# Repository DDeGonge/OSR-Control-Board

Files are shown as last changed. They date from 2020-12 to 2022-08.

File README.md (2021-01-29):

# OSR-Control-Board
Open Source Robotics Control Board - The cheap, overpowered, easy to use robotics controller.

## BOM
Latest BOM can be found [here](https://octopart.com/bom-tool/g8IoScnJ)

## Bootloader
Flashing instructions are found [here](https://learn.adafruit.com/how-to-program-samd-bootloaders/programming-the-bootloader-with-atmel-studio). Follow directions for Feather M4. Notch on flex cable faces AWAY from mcu.

## Random Stuff
Generate MD5 sum for packages - `CertUtil -hashfile C:\TEMP\MyDataFile.img MD5`

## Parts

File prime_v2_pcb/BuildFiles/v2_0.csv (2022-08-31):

Id | Designator | Package | Quantity | Designation | Supplier and ref
1 | J10,J6,J3,J9,J7,J5,J4,J1 | PinHeader_1x04_P2.54mm_Vertical | 8 | Conn_01x04
2 | J14,J12,J11,J8 | PinHeader_1x05_P2.54mm_Vertical | 4 | Conn_01x05
3 | A1,A3,A2 | Pololu_Breakout-20_15.2x20.3mm | 3 | Pololu_Breakout_TMC5160
4 | C3,C2,C1,C49,C19,C30 | CP_Elec_6.3x7.7 | 6 | 47uF
5 | C31 | C_0805_2012Metric | 1 | 10uF
6 | U3 | MUB_v1 | 1 | MUBv1
7 | U2,U1 | QFN-48-1EP_7x7mm_P0.5mm_EP5.3x5.3mm | 2 | TMC2041-LA
8 | J2 | 691313710002 | 1 | 691313710002
9 | G*** | smol_logo | 1 | LOGO
10 | G*** | logo | 1 | LOGO
11 | R12,R11,R10,R9,R7,R6,R5,R4 | R_0805_2012Metric | 8 | 0R2
12 | R8,R3 | R_0603_1608Metric | 2 | 2R2
13 | C50,C42,C27,C22,C21,C20,C18,C17,C13,C12 | C_0603_1608Metric | 10 | 100nF
14 | C26,C16 | C_0603_1608Metric | 2 | 22nF
15 | C24,C15 | C_0603_1608Metric | 2 | 470nF
16 | C23,C14 | C_1206_3216Metric | 2 | 2.2uF
17 | J22 | PinSocket_1x06_P2.54mm_Vertical | 1 | Conn_01x06
18 | J16,J15 | PinHeader_1x03_P2.54mm_Vertical | 2 | Conn_01x03
19 | J20,J19,J18,J17 | MountingHole_2.7mm_M2.5_DIN965_Pad | 4 | Hole
20 | J13 | PinHeader_1x10_P2.54mm_Vertical | 1 | Conn_01x10

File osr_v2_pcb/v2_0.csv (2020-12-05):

Id | Designator | Package | Quantity | Designation | Supplier and ref
1 | J6 | 2002112100010C4LF | 1 | 20021121-00010C4LF
2 | R22,R18,R16,R15,R2,R1 | R_0603_1608Metric | 6 | 10k
3 | R21 | R_0603_1608Metric | 1 | 100k
4 | J1 | 475710001 | 1 | 47571-0001
5 | L3,L2,L1 | L_0805_2012Metric | 3 | 10uH
6 | IC1 | SOT95P280X100-6N | 1 | AP63205WU-7
7 | C36,C35,C34,C31,C2 | C_0805_2012Metric | 5 | 10uF
8 | C7,C11,C10,C9,C8,C6,C5,C3,C1 | C_0603_1608Metric | 9 | 1uF
9 | C4,C28,C27,C25,C22,C21,C19,C18,C16,C13,C12 | C_0603_1608Metric | 11 | 100nF
10 | J22 | PinSocket_1x06_P2.54mm_Vertical | 1 | Conn_01x06
11 | J7,J21,J9,J8 | PinHeader_1x02_P2.54mm_Vertical | 4 | Conn_01x02
12 | D4,D3 | D_SOD-123F | 2 | CGRTS4004-HF
13 | R20,R19,R14,R13,R17 | R_0603_1608Metric | 5 | 174
14 | D2,D1 | LED_0603_1608Metric | 2 | LED
15 | G*** | smol_logo | 1 | LOGO
16 | G*** | logo | 1 | LOGO
17 | IC2 | QFN-64-1EP_9x9mm_P0.5mm_EP6x6mm_ThermalVias | 1 | ATSAMD51J19A-MU
18 | S1 | KMR421GULCLFS | 1 | KMR243GLFG
19 | J11,J10,J5,J4 | PinHeader_1x04_P2.54mm_Vertical | 4 | Conn_01x04
20 | J14 | PinSocket_1x20_P2.54mm_Vertical | 1 | Conn_01x20
21 | J16,J15,J13,J12 | PinHeader_1x03_P2.54mm_Vertical | 4 | Conn_01x03
22 | C33,C32 | C_0603_1608Metric | 2 | 22pF
23 | J2 | BarrelJack_Wuerth_6941xx301002 | 1 | Conn_01x02
24 | Y1 | LFXTAL009678REEL | 1 | LFXTAL009678REEL
25 | Q2,Q1 | NVTFS6H854NTAG | 2 | NVTFS5C680NLTAG
26 | R12,R11,R10,R9,R7,R6,R5,R4 | R_0805_2012Metric | 8 | 0R2
27 | R8,R3 | R_0603_1608Metric | 2 | 2R2
28 | C30,C29,C20 | CP_Elec_6.3x7.7 | 3 | 47uF
29 | C26,C17 | C_0603_1608Metric | 2 | 22nF
30 | C24,C15 | C_0603_1608Metric | 2 | 470nF
31 | C23,C14 | C_1206_3216Metric | 2 | 4.7uF
32 | U3 | SOT-23-5 | 1 | AP2112K-3.3
33 | J3 | 47346-0001 | 1 | 47346-0001
34 | U2,U1 | QFN-48-1EP_7x7mm_P0.5mm_EP5.3x5.3mm_ThermalVias | 2 | TMC2041-LA
35 | J20,J19,J18,J17 | MountingHole_2.7mm_M2.5_DIN965_Pad | 4 | Hole

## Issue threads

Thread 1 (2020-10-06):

No general use power/ground pins

DDeGonge, 2020-10-06:
Add some 3v3, 5v, vin, and gnd pins in a cluster somewhere so peripherals can more easily access power and ground

DDeGonge, 2020-10-10:
Added 1x VDC, 1x 5v, 2x 3v3, 2x gnd to a new header

Closed 2020-10-10.

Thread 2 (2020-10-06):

Add better stepper driver protection

DDeGonge, 2020-10-06:
Low hanging fruit is added esd protection. But maybe also add varistors for protection against accidental disconnects while powered.

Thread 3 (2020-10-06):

Upgrade generic gate mosfets

DDeGonge, 2020-10-06:
Use DMT3006LDK-7 instead of NVTFS5C680NLTAG

30V instead of 60V which makes more sense for this pcb that operates at 6-24v
17A continuous instead of 8A because...more better
Only a few cents more

DDeGonge, 2020-11-18:
DMT3006LDK-7 has stock problems and I don't know why I'd ever need such a high power gate..but will leave this open for future changes

Closed 2020-11-18.

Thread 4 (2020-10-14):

Add better battery support

DDeGonge, 2020-10-14:
Include a voltage divider so battery voltage can be measured directly, with support for up to a 6s battery.

Stretch goal is to add balance charger but this will probably be too expensive.

DDeGonge, 2020-12-05:
hooked up vin voltage divider to B1 (pin 62)

Closed 2020-12-05.

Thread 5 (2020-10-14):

Add fuse protection on input

DDeGonge, 2020-10-14:
Safety is number one priority.

Not sure of the value since this board is hangry for power.

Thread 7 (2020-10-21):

Find black sense resistors

DDeGonge, 2020-10-21:
The green ones are ugly and I'm vain

DDeGonge, 2020-10-27:
Replaced with ERJ-6DSFR20V. Also now 1/2W instead of 1/3W.

Closed 2020-10-27.

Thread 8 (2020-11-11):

Change 5V reg from linear to buck

DDeGonge, 2020-11-11:
5V isn't actually used by any onboard devices so it's fine if it isn't perfectly stable. Retain lreg for 3v3 line.

Closed 2020-11-18.

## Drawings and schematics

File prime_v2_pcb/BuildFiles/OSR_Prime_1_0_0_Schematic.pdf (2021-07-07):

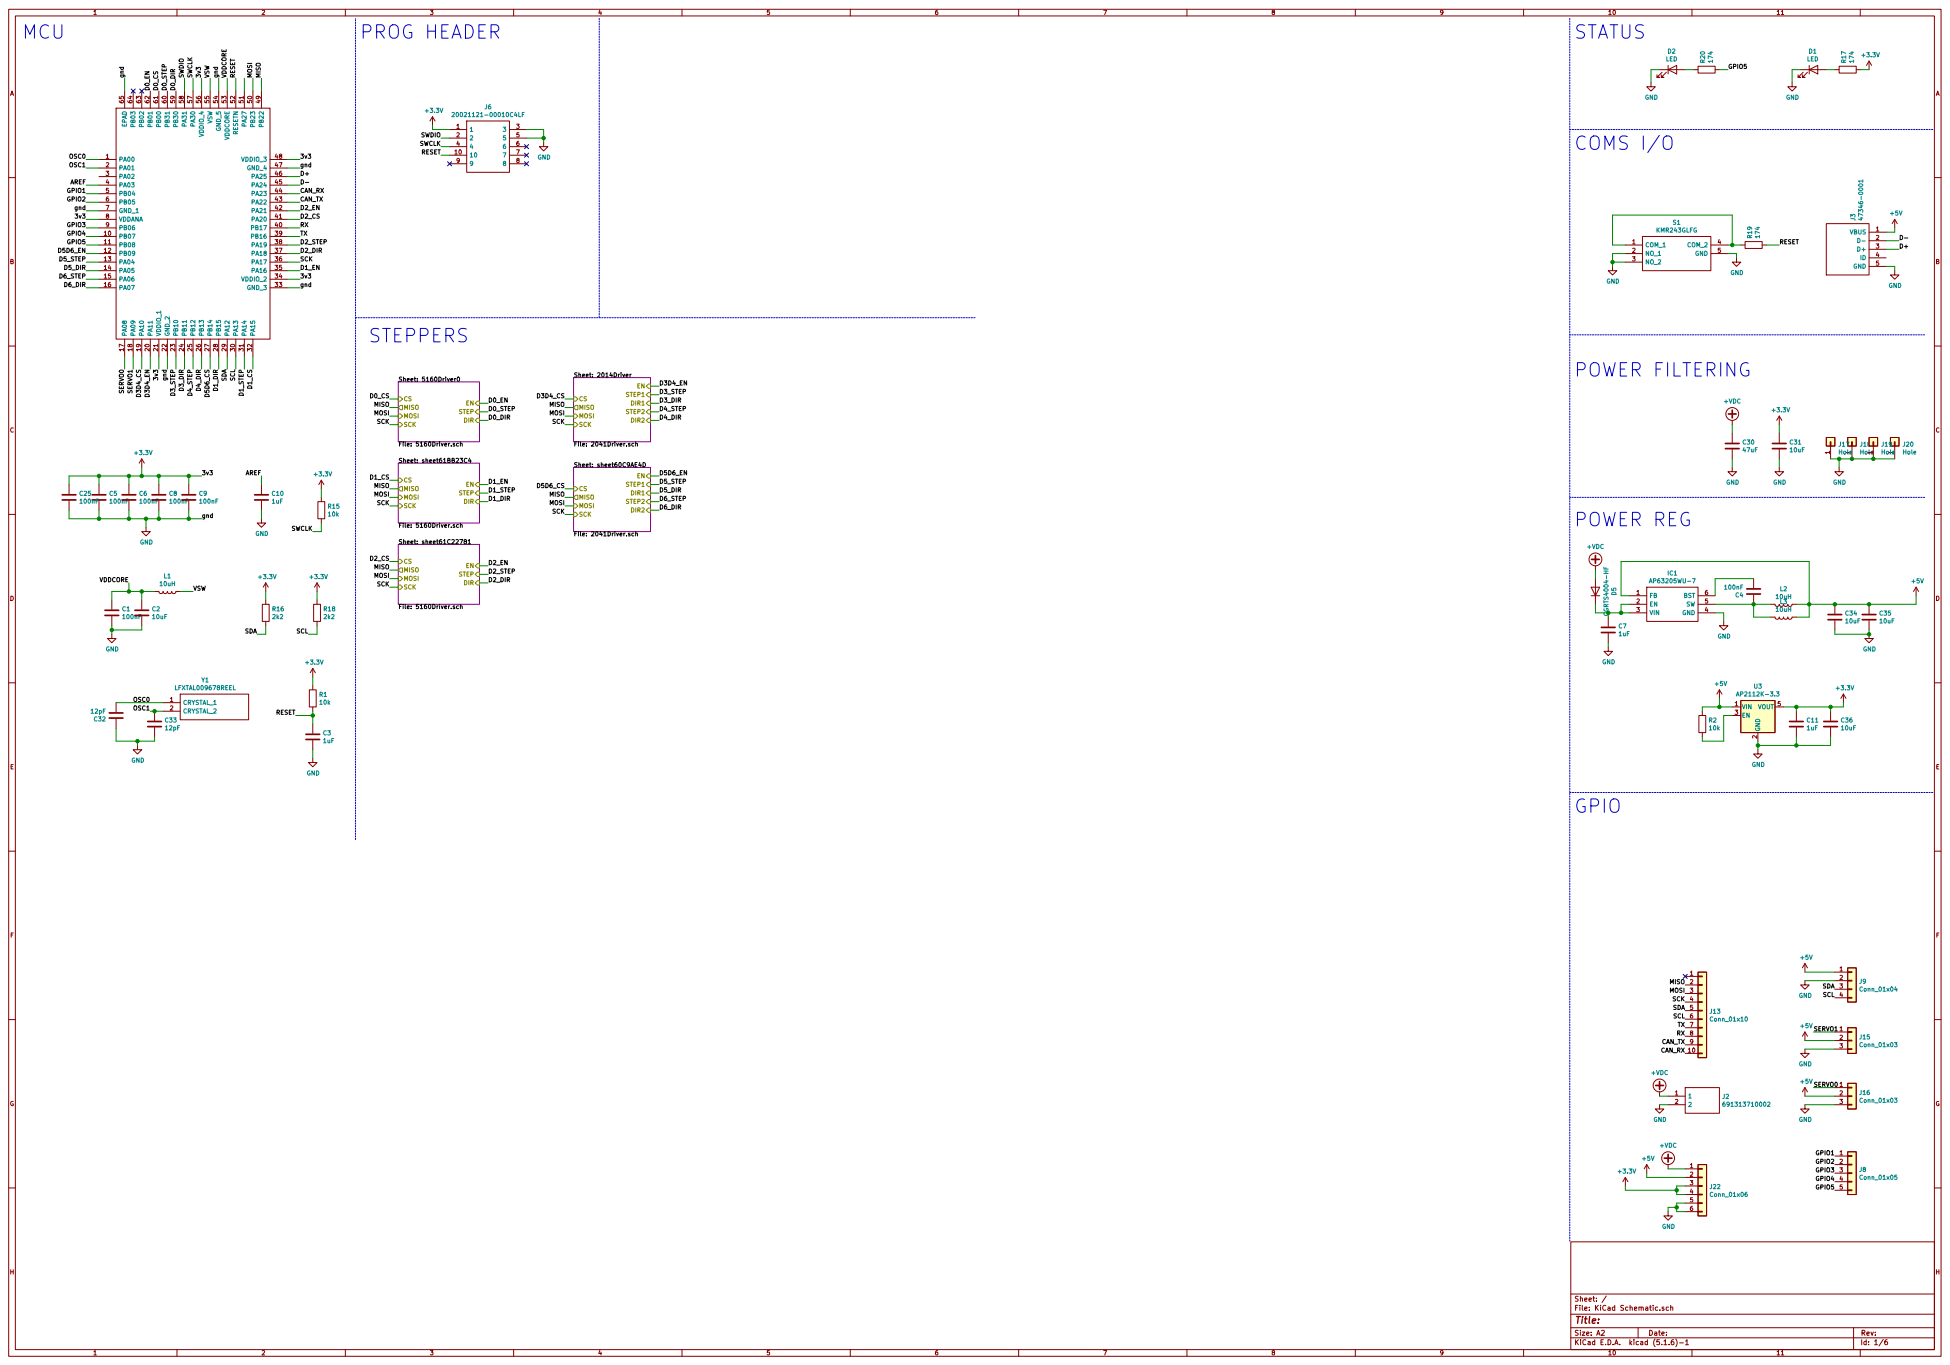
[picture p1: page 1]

Sheet: 5160Driver0 File: 5160Driver.sch SCK MOSI MISO

Sheet: sheet61BB23C4 File: 5160Driver.sch SCK MOSI MISO

Sheet: sheet61C22781 File: 5160Driver.sch SCK MOSI MISO

Id: 1/6 Title: File: KiCad Schematic.sch Sheet: /

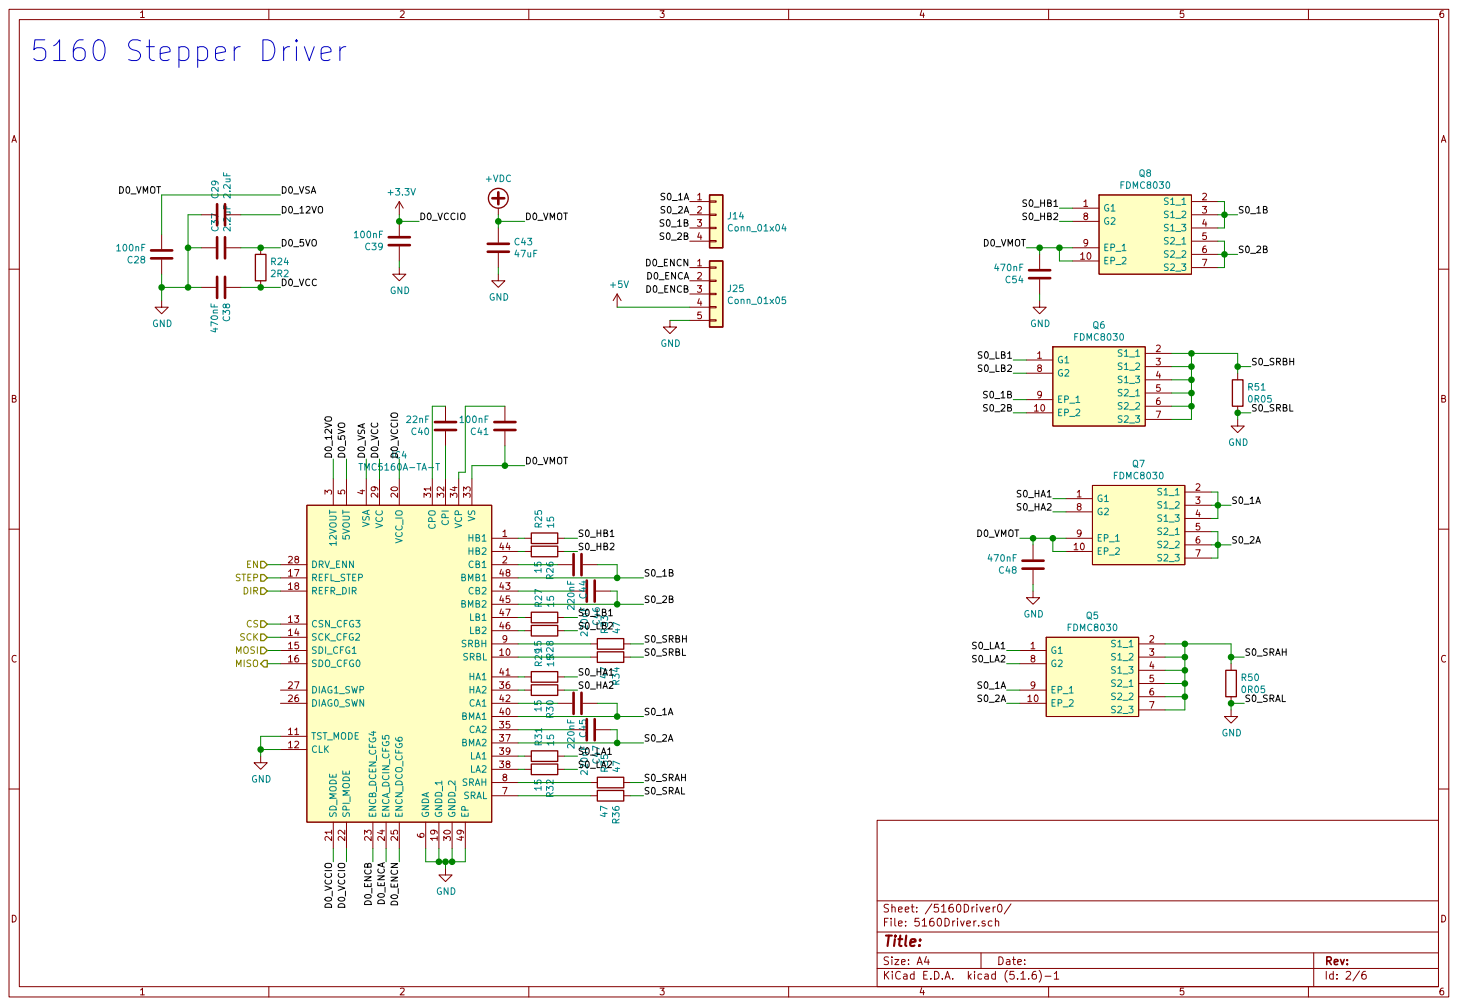
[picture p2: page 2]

EN MISO MOSI CS
STEP
SCK DIR

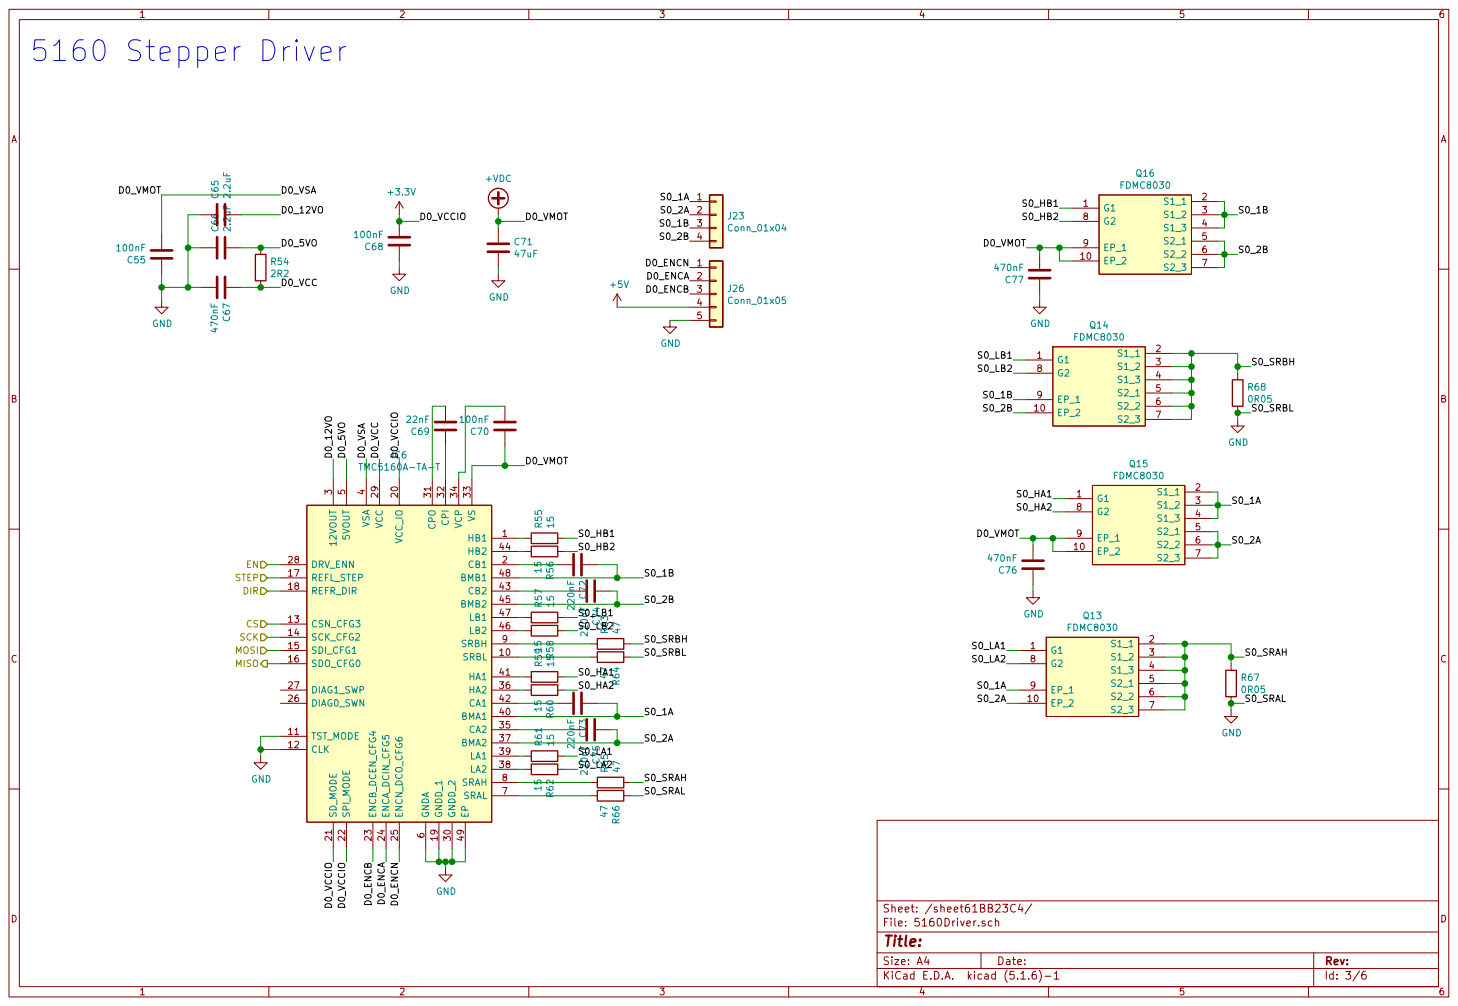
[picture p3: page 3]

EN MISO MOSI CS
STEP
SCK DIR

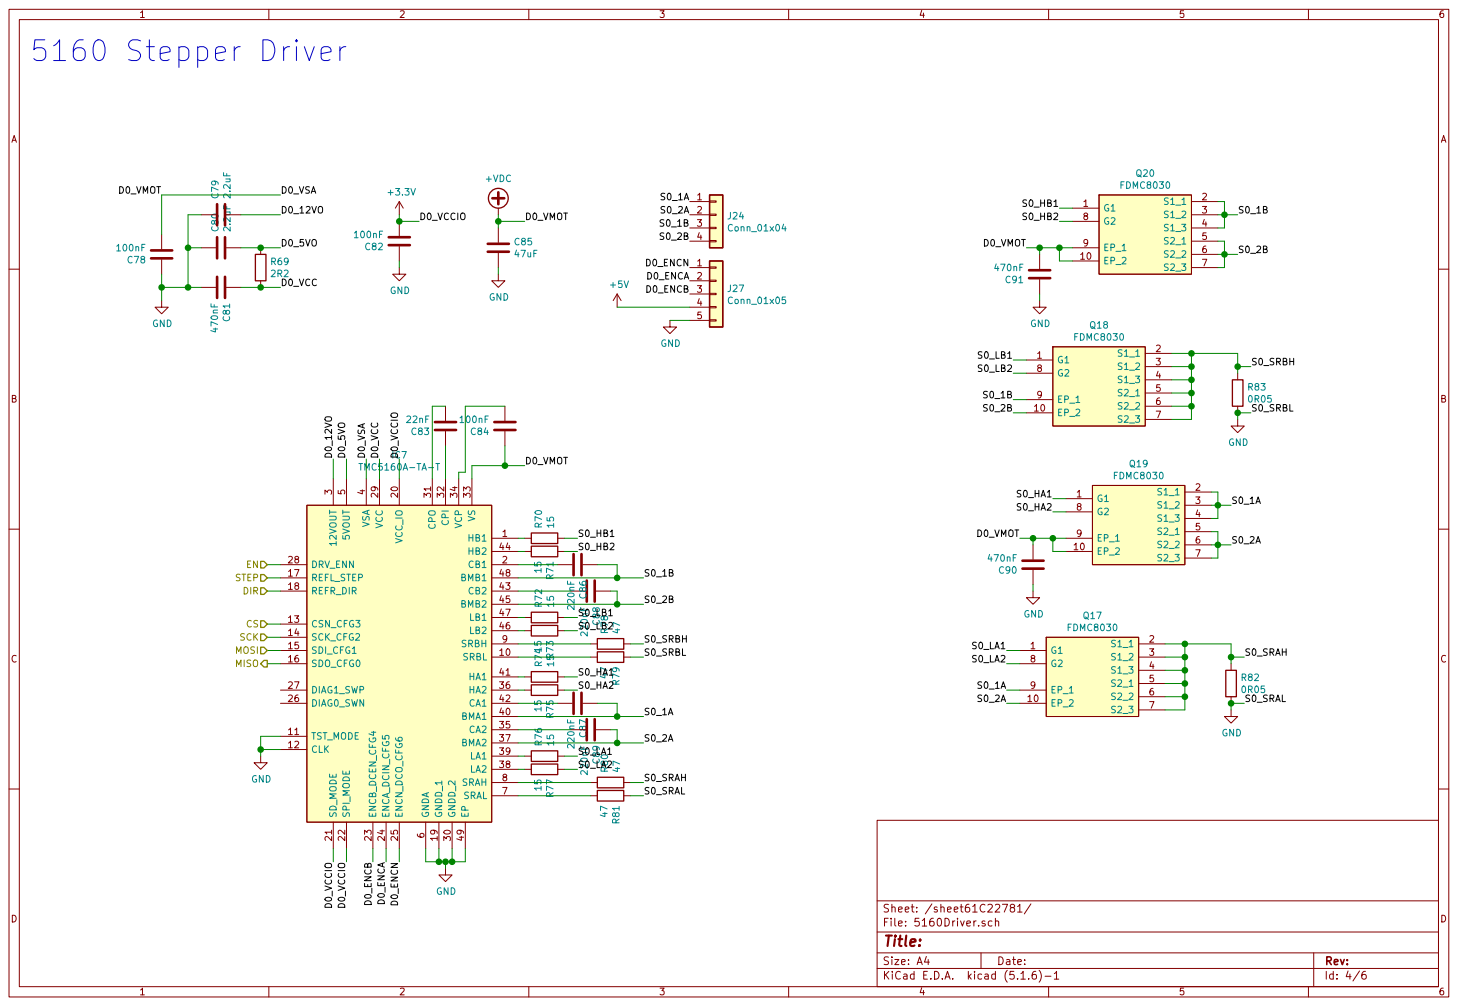
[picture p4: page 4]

EN MISO MOSI CS
STEP
SCK DIR

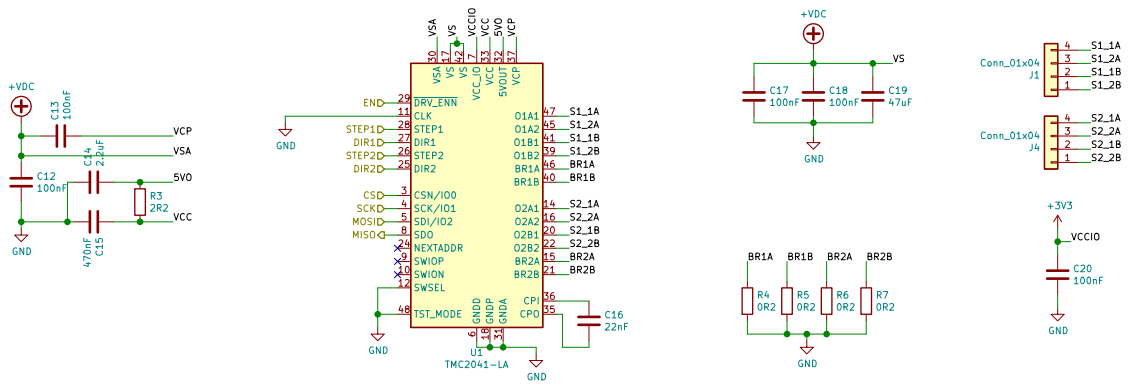
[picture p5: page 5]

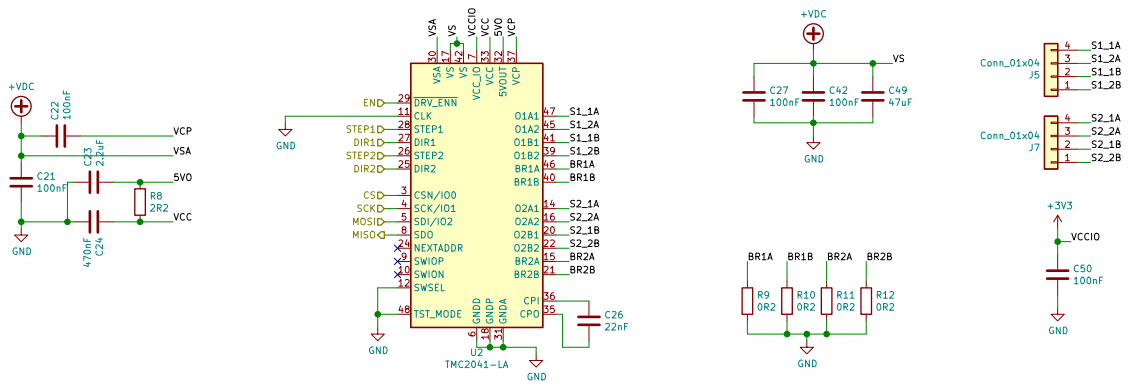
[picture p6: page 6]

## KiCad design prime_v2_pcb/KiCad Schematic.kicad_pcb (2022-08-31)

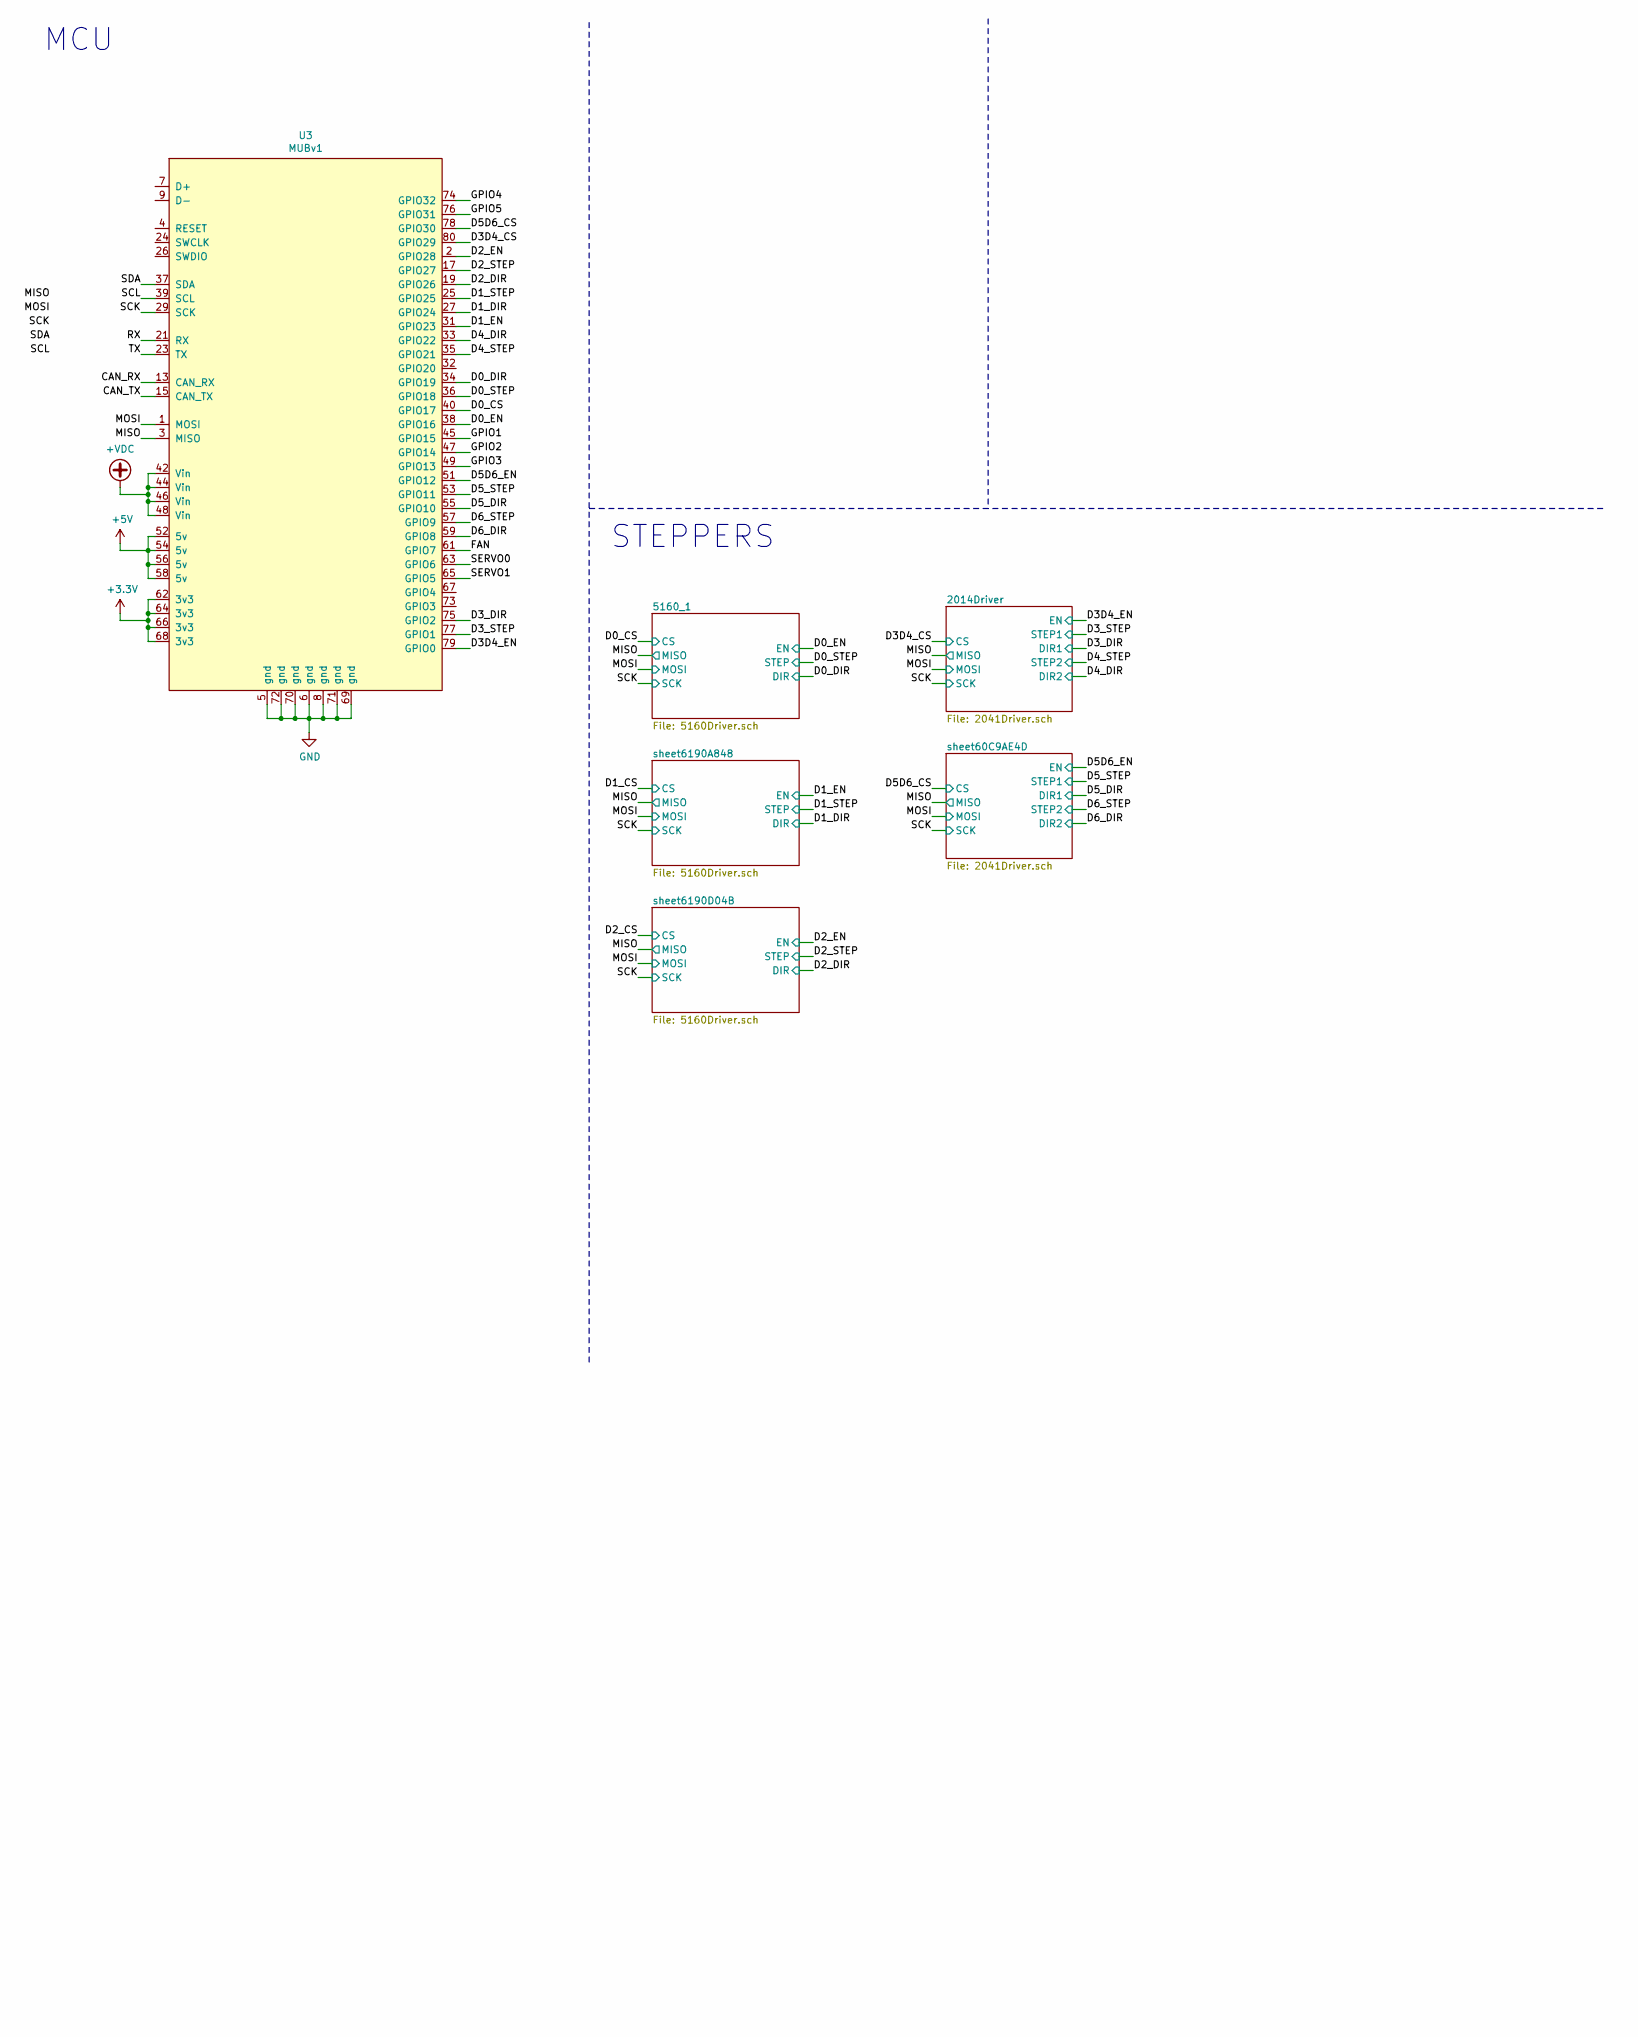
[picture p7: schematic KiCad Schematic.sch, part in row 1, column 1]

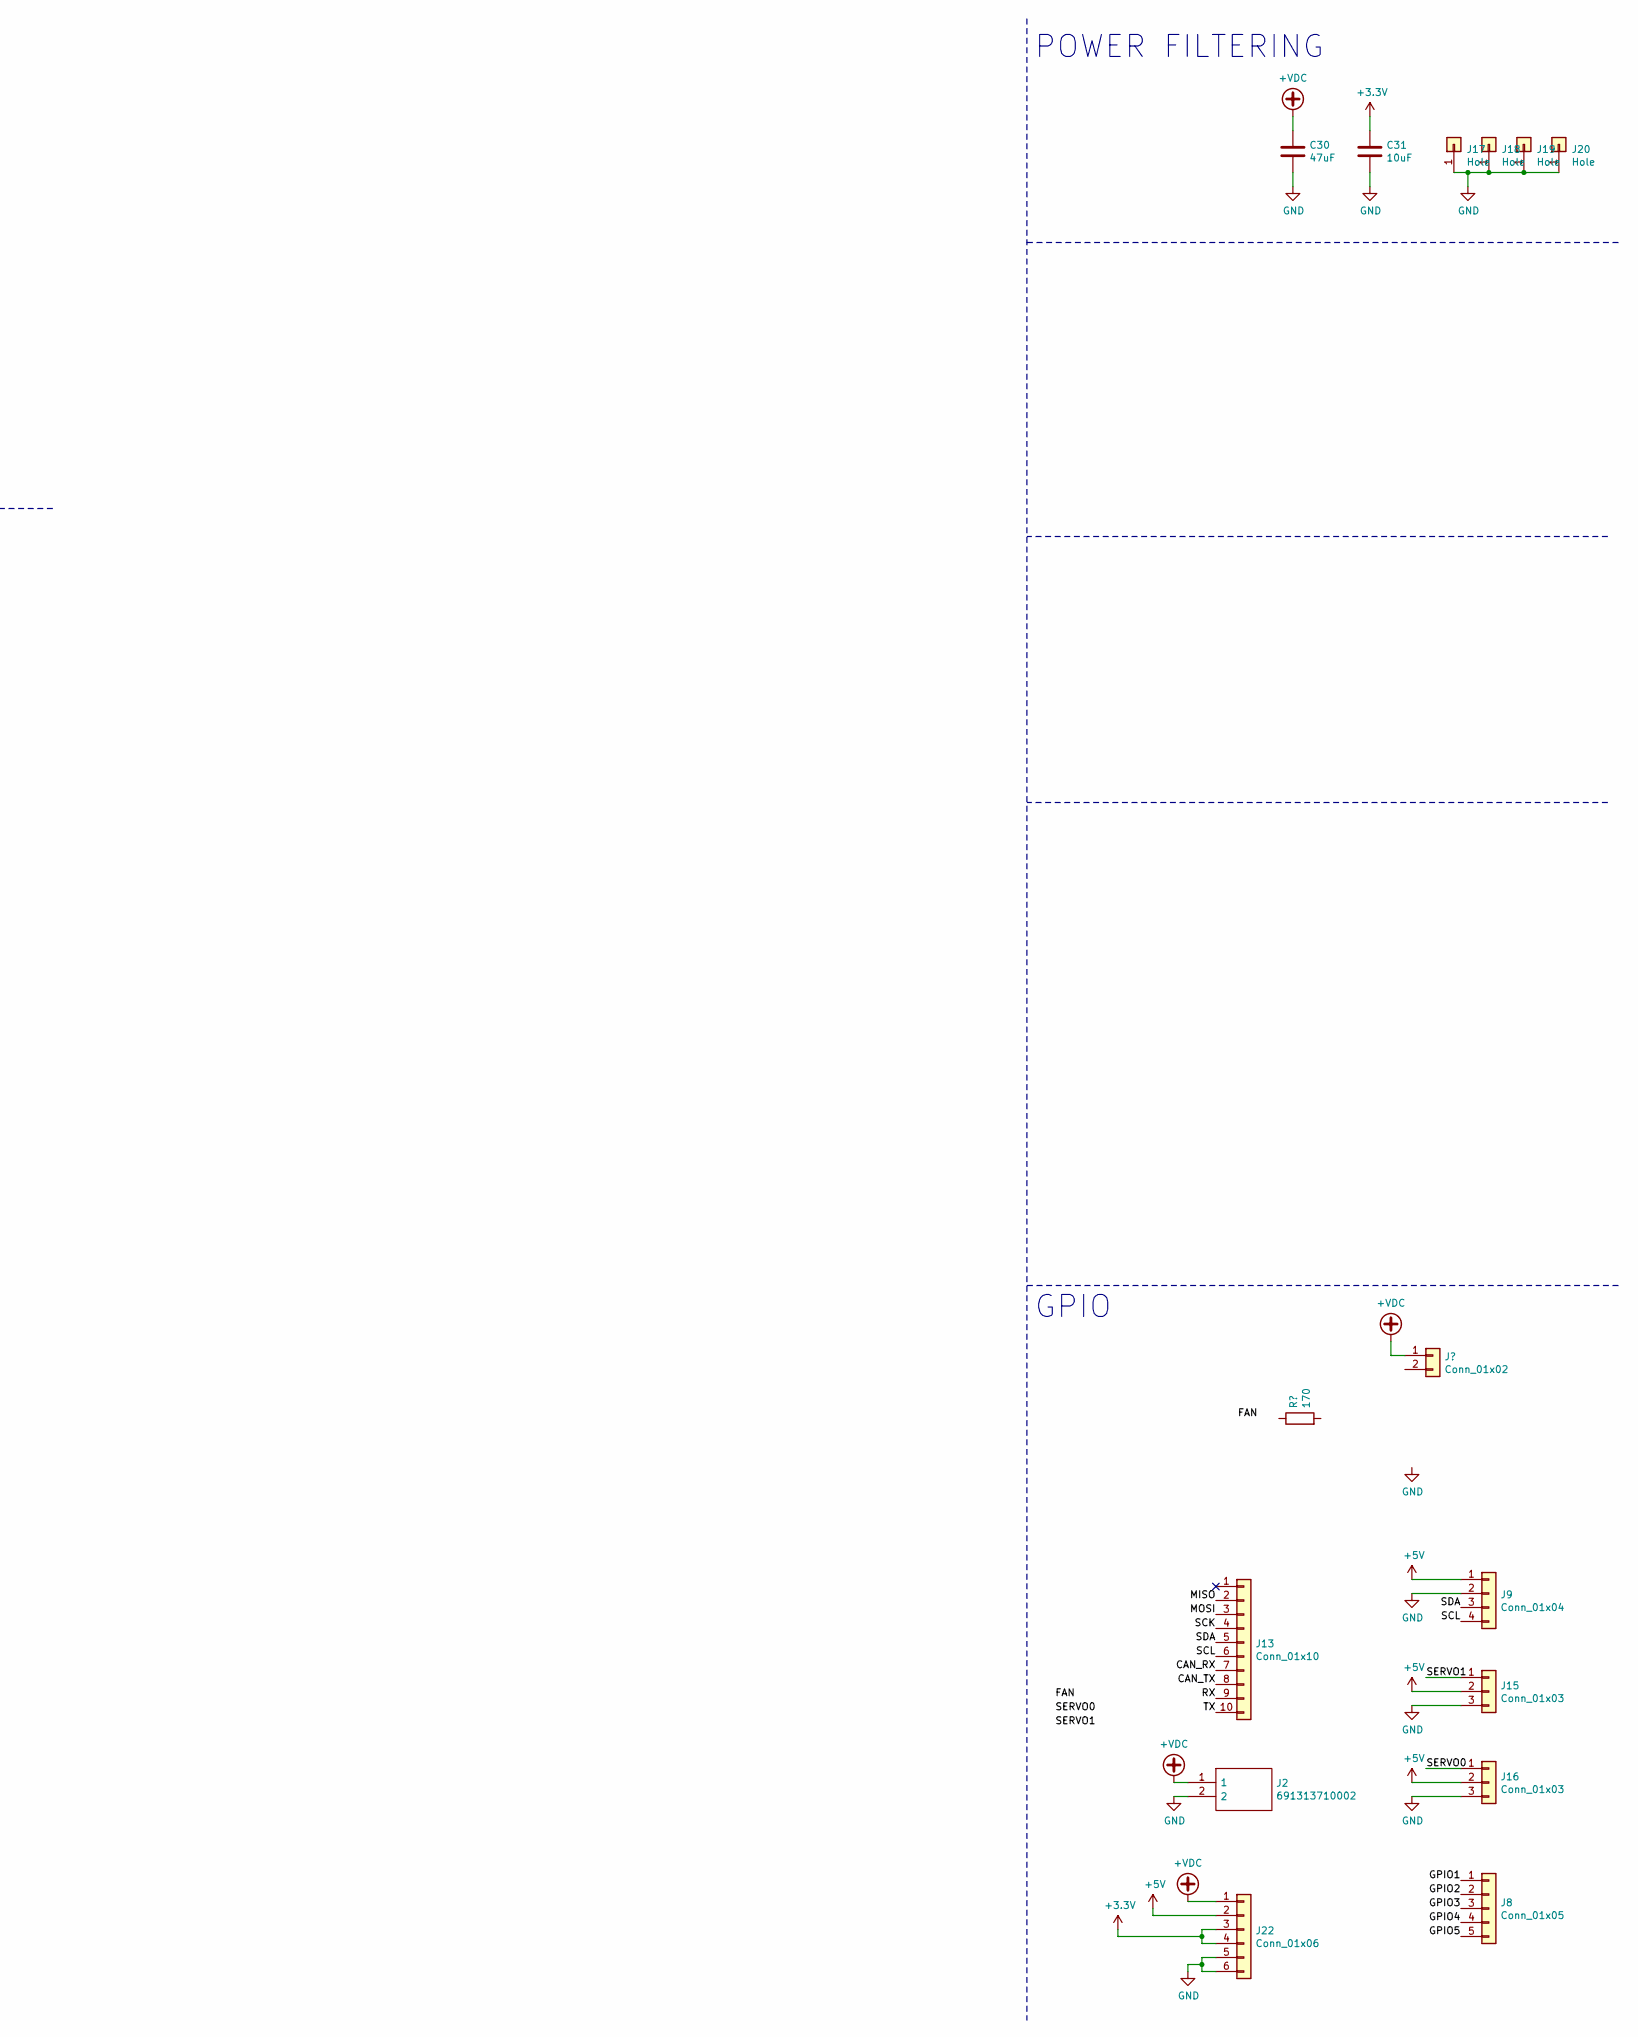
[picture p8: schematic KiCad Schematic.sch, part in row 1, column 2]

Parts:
C30: 47uF; CP_Elec_6.3x7.7
C31: 10uF; C_0805_2012Metric
J2: 691313710002; Mouser Part Number 710-691313710002
J8: Conn_01x05; PinHeader_1x05_P2.54mm_Vertical
J9: Conn_01x04; PinHeader_1x04_P2.54mm_Vertical
J13: Conn_01x10; PinHeader_1x10_P2.54mm_Vertical
J15, J16: Conn_01x03; PinHeader_1x03_P2.54mm_Vertical
J17, J18, J19, J20: Hole; MountingHole_2.7mm_M2.5_DIN965_Pad
J22: Conn_01x06; PinSocket_1x06_P2.54mm_Vertical
U3: MUBv1; MUB_v1

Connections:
+5V: J9.1, J15.2, J16.2, J22.2, U3.52 (5v), U3.54 (5v), U3.56 (5v), U3.58 (5v)
+VDC: C30.1, J2.1, J22.1, U3.42 (Vin), U3.44 (Vin), U3.46 (Vin), U3.48 (Vin); also elsewhere on the board
/CAN_RX: J13.7, U3.13 (CAN_RX)
/CAN_TX: J13.8, U3.15 (CAN_TX)
/D0_CS: U3.40 (GPIO17); also elsewhere on the board
/D0_DIR: U3.34 (GPIO19); also elsewhere on the board
/D0_EN: U3.38 (GPIO16); also elsewhere on the board
/D0_STEP: U3.36 (GPIO18); also elsewhere on the board
/D1_DIR: U3.27 (GPIO24); also elsewhere on the board
/D1_EN: U3.31 (GPIO23); also elsewhere on the board
/D1_STEP: U3.25 (GPIO25); also elsewhere on the board
/D2_DIR: U3.19 (GPIO26); also elsewhere on the board
/D2_EN: U3.2 (GPIO28); also elsewhere on the board
/D2_STEP: U3.17 (GPIO27); also elsewhere on the board
/D3D4_CS: U3.80 (GPIO29); also elsewhere on the board
/D3D4_EN: U3.79 (GPIO0); also elsewhere on the board
/D3_DIR: U3.75 (GPIO2); also elsewhere on the board
/D3_STEP: U3.77 (GPIO1); also elsewhere on the board
/D4_DIR: U3.33 (GPIO22); also elsewhere on the board
/D4_STEP: U3.35 (GPIO21); also elsewhere on the board
/D5D6_CS: U3.78 (GPIO30); also elsewhere on the board
/D5D6_EN: U3.51 (GPIO12); also elsewhere on the board
/D5_DIR: U3.55 (GPIO10); also elsewhere on the board
/D5_STEP: U3.53 (GPIO11); also elsewhere on the board
/D6_DIR: U3.59 (GPIO8); also elsewhere on the board
/D6_STEP: U3.57 (GPIO9); also elsewhere on the board
/GPIO1: J8.1, U3.45 (GPIO15)
/GPIO2: J8.2, U3.47 (GPIO14)
/GPIO3: J8.3, U3.49 (GPIO13)
/GPIO4: J8.4, U3.74 (GPIO32)
/GPIO5: J8.5, U3.76 (GPIO31)
/MISO: J13.2, U3.3 (MISO); also elsewhere on the board
/MOSI: J13.3, U3.1 (MOSI); also elsewhere on the board
/RX: J13.9, U3.21 (RX)
/SCK: J13.4, U3.29 (SCK); also elsewhere on the board
/SCL: J9.4, J13.6, U3.39 (SCL)
/SDA: J9.3, J13.5, U3.37 (SDA)
/TX: J13.10, U3.23 (TX)
GND: C30.2, C31.2, J2.2, J9.2, J15.3, J16.3, J17.1, J18.1, J19.1, J20.1, J22.5, J22.6, U3.5 (gnd), U3.6 (gnd), U3.8 (gnd), U3.69 (gnd), U3.70 (gnd), U3.71 (gnd), U3.72 (gnd); also elsewhere on the board

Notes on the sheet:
GPIO
POWER FILTERING
MCU
STEPPERS

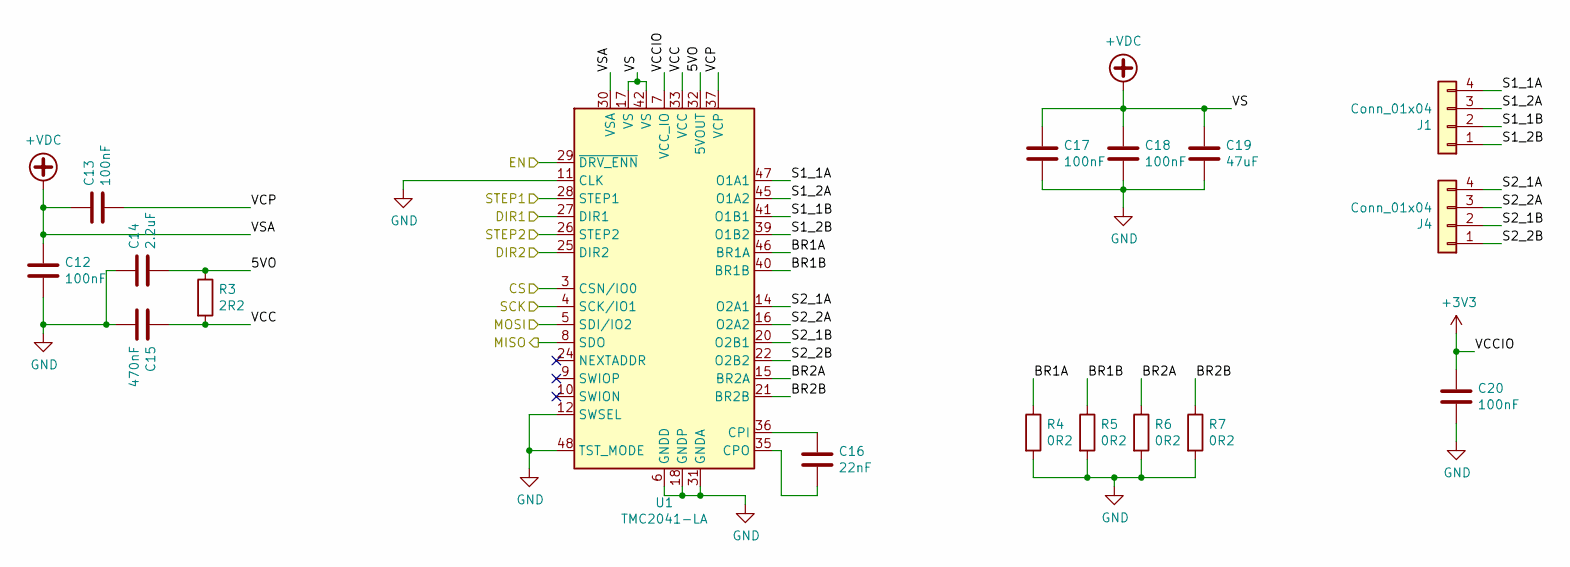
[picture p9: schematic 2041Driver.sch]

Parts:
C12, C13, C17, C18, C20: 100nF; C_0603_1608Metric
C14: 2.2uF; C_1206_3216Metric
C15: 470nF; C_0603_1608Metric
C16: 22nF; C_0603_1608Metric
C19: 47uF; CP_Elec_6.3x7.7
J1, J4: Conn_01x04; PinHeader_1x04_P2.54mm_Vertical
R3: 2R2; R_0603_1608Metric
R4, R5, R6, R7: 0R2; R_0805_2012Metric
U1: TMC2041-LA; QFN-48-1EP_7x7mm_P0.5mm_EP5.3x5.3mm

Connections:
+VDC: C12.1, C13.1, C17.1, C18.1, C19.1, U1.17 (VS), U1.19 (VS), U1.30 (VSA), U1.42 (VS), U1.44 (VS); also elsewhere on the board
/2014Driver/5VO: C14.2, R3.1, U1.32 (5VOUT)
/2014Driver/BR1A: R4.1, U1.46 (BR1A)
/2014Driver/BR1B: R5.1, U1.40 (BR1B)
/2014Driver/BR2A: R6.1, U1.15 (BR2A)
/2014Driver/BR2B: R7.1, U1.21 (BR2B)
/2014Driver/S1_1A: J1.4, U1.47 (O1A1)
/2014Driver/S1_1B: J1.2, U1.41 (O1B1)
/2014Driver/S1_2A: J1.3, U1.45 (O1A2)
/2014Driver/S1_2B: J1.1, U1.39 (O1B2)
/2014Driver/S2_1A: J4.4, U1.14 (O2A1)
/2014Driver/S2_1B: J4.2, U1.20 (O2B1)
/2014Driver/S2_2A: J4.3, U1.16 (O2A2)
/2014Driver/S2_2B: J4.1, U1.22 (O2B2)
/2014Driver/VCC: C15.1, R3.2, U1.33 (VCC)
/2014Driver/VCP: C13.2, U1.37 (VCP)
/D3D4_CS: U1.3 (CSN/IO0); also elsewhere on the board
/D3D4_EN: U1.29 (~DRV_ENN); also elsewhere on the board
/D3_DIR: U1.27 (DIR1); also elsewhere on the board
/D3_STEP: U1.28 (STEP1); also elsewhere on the board
/D4_DIR: U1.25 (DIR2); also elsewhere on the board
/D4_STEP: U1.26 (STEP2); also elsewhere on the board
/MISO: U1.8 (SDO); also elsewhere on the board
/MOSI: U1.5 (SDI/IO2); also elsewhere on the board
/SCK: U1.4 (SCK/IO1); also elsewhere on the board
GND: C12.2, C14.1, C15.2, C17.2, C18.2, C19.2, C20.2, R4.2, R5.2, R6.2, R7.2, U1.1 (GNDD), U1.2 (GNDD), U1.6 (GNDD), U1.11 (CLK), U1.12 (SWSEL), U1.13 (GNDD), U1.18 (GNDP), U1.23 (GNDD), U1.31 (GNDA), U1.34 (GNDD), U1.38 (GNDD), U1.43 (GNDP), U1.48 (TST_MODE), U1.49 (GNDD); also elsewhere on the board
unnamed: C16.1, U1.36 (CPI)
unnamed: C16.2, U1.35 (CPO)

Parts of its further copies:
C21, C22, C27, C42, C50: 100nF; C_0603_1608Metric
C23: 2.2uF; C_1206_3216Metric
C24: 470nF; C_0603_1608Metric
C26: 22nF; C_0603_1608Metric
C49: 47uF; CP_Elec_6.3x7.7
J5, J7: Conn_01x04; PinHeader_1x04_P2.54mm_Vertical
R8: 2R2; R_0603_1608Metric
R9, R10, R11, R12: 0R2; R_0805_2012Metric
U2: TMC2041-LA; QFN-48-1EP_7x7mm_P0.5mm_EP5.3x5.3mm

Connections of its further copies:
+VDC: C21.1, C22.1, C27.1, C42.1, C49.1, U2.17 (VS), U2.19 (VS), U2.30 (VSA), U2.42 (VS), U2.44 (VS); also elsewhere on the board
/D5D6_CS: U2.3 (CSN/IO0); also elsewhere on the board
/D5D6_EN: U2.29 (~DRV_ENN); also elsewhere on the board
/D5_DIR: U2.27 (DIR1); also elsewhere on the board
/D5_STEP: U2.28 (STEP1); also elsewhere on the board
/D6_DIR: U2.25 (DIR2); also elsewhere on the board
/D6_STEP: U2.26 (STEP2); also elsewhere on the board
/MISO: U2.8 (SDO); also elsewhere on the board
/MOSI: U2.5 (SDI/IO2); also elsewhere on the board
/SCK: U2.4 (SCK/IO1); also elsewhere on the board
/sheet60C9AE4D/5VO: C23.2, R8.1, U2.32 (5VOUT)
/sheet60C9AE4D/BR1A: R9.1, U2.46 (BR1A)
/sheet60C9AE4D/BR1B: R10.1, U2.40 (BR1B)
/sheet60C9AE4D/BR2A: R11.1, U2.15 (BR2A)
/sheet60C9AE4D/BR2B: R12.1, U2.21 (BR2B)
/sheet60C9AE4D/S1_1A: J5.4, U2.47 (O1A1)
/sheet60C9AE4D/S1_1B: J5.2, U2.41 (O1B1)
/sheet60C9AE4D/S1_2A: J5.3, U2.45 (O1A2)
/sheet60C9AE4D/S1_2B: J5.1, U2.39 (O1B2)
/sheet60C9AE4D/S2_1A: J7.4, U2.14 (O2A1)
/sheet60C9AE4D/S2_1B: J7.2, U2.20 (O2B1)
/sheet60C9AE4D/S2_2A: J7.3, U2.16 (O2A2)
/sheet60C9AE4D/S2_2B: J7.1, U2.22 (O2B2)
/sheet60C9AE4D/VCC: C24.1, R8.2, U2.33 (VCC)
/sheet60C9AE4D/VCP: C22.2, U2.37 (VCP)
GND: C21.2, C23.1, C24.2, C27.2, C42.2, C49.2, C50.2, R9.2, R10.2, R11.2, R12.2, U2.1 (GNDD), U2.2 (GNDD), U2.6 (GNDD), U2.11 (CLK), U2.12 (SWSEL), U2.13 (GNDD), U2.18 (GNDP), U2.23 (GNDD), U2.31 (GNDA), U2.34 (GNDD), U2.38 (GNDD), U2.43 (GNDP), U2.48 (TST_MODE), U2.49 (GNDD); also elsewhere on the board
unnamed: C26.1, U2.36 (CPI)
unnamed: C26.2, U2.35 (CPO)

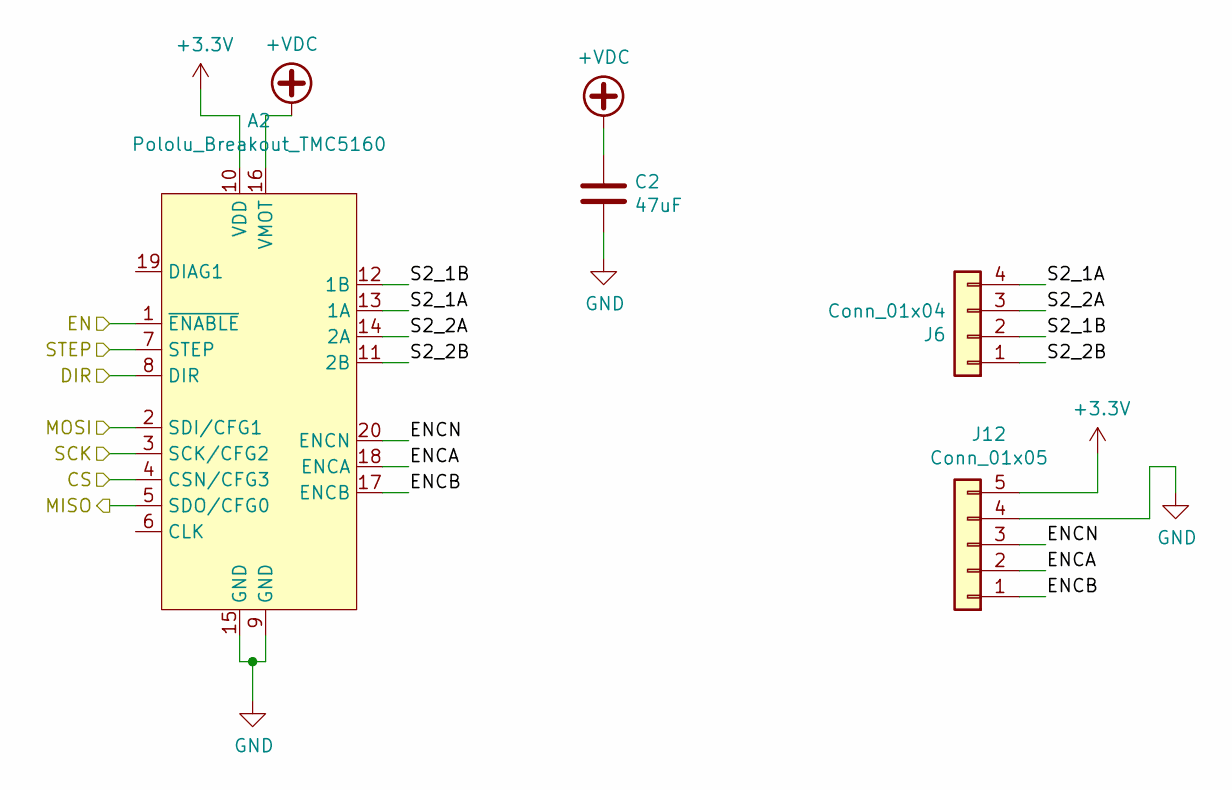
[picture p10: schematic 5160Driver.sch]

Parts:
A1: Pololu_Breakout_TMC5160; Pololu_Breakout-20_15.2x20.3mm
C1: 47uF; CP_Elec_6.3x7.7
J3: Conn_01x04; PinHeader_1x04_P2.54mm_Vertical
J11: Conn_01x05; PinHeader_1x05_P2.54mm_Vertical

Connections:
+VDC: A1.16 (VMOT), C1.1; also elsewhere on the board
/5160_1/ENCA: A1.18 (ENCA), J11.2
/5160_1/ENCB: A1.17 (ENCB), J11.1
/5160_1/ENCN: A1.20 (ENCN), J11.3
/5160_1/S2_1A: A1.13 (1A), J3.4
/5160_1/S2_1B: A1.12 (1B), J3.2
/5160_1/S2_2A: A1.14 (2A), J3.3
/5160_1/S2_2B: A1.11 (2B), J3.1
/D0_CS: A1.4 (CSN/CFG3); also elsewhere on the board
/D0_DIR: A1.8 (DIR); also elsewhere on the board
/D0_EN: A1.1 (~ENABLE); also elsewhere on the board
/D0_STEP: A1.7 (STEP); also elsewhere on the board
/MISO: A1.5 (SDO/CFG0); also elsewhere on the board
/MOSI: A1.2 (SDI/CFG1); also elsewhere on the board
/SCK: A1.3 (SCK/CFG2); also elsewhere on the board
GND: A1.9 (GND), A1.15 (GND), C1.2, J11.4; also elsewhere on the board

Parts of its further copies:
A2, A3: Pololu_Breakout_TMC5160; Pololu_Breakout-20_15.2x20.3mm
C2, C3: 47uF; CP_Elec_6.3x7.7
J6, J10: Conn_01x04; PinHeader_1x04_P2.54mm_Vertical
J12, J14: Conn_01x05; PinHeader_1x05_P2.54mm_Vertical

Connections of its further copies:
+VDC: A2.16 (VMOT), A3.16 (VMOT), C2.1, C3.1; also elsewhere on the board
/D1_CS: A2.4 (CSN/CFG3)
/D1_DIR: A2.8 (DIR); also elsewhere on the board
/D1_EN: A2.1 (~ENABLE); also elsewhere on the board
/D1_STEP: A2.7 (STEP); also elsewhere on the board
/D2_CS: A3.4 (CSN/CFG3)
/D2_DIR: A3.8 (DIR); also elsewhere on the board
/D2_EN: A3.1 (~ENABLE); also elsewhere on the board
/D2_STEP: A3.7 (STEP); also elsewhere on the board
/MISO: A2.5 (SDO/CFG0), A3.5 (SDO/CFG0); also elsewhere on the board
/MOSI: A2.2 (SDI/CFG1), A3.2 (SDI/CFG1); also elsewhere on the board
/SCK: A2.3 (SCK/CFG2), A3.3 (SCK/CFG2); also elsewhere on the board
/sheet6190A848/ENCA: A2.18 (ENCA), J12.2
/sheet6190A848/ENCB: A2.17 (ENCB), J12.1
/sheet6190A848/ENCN: A2.20 (ENCN), J12.3
/sheet6190A848/S2_1A: A2.13 (1A), J6.4
/sheet6190A848/S2_1B: A2.12 (1B), J6.2
/sheet6190A848/S2_2A: A2.14 (2A), J6.3
/sheet6190A848/S2_2B: A2.11 (2B), J6.1
/sheet6190D04B/ENCA: A3.18 (ENCA), J14.2
/sheet6190D04B/ENCB: A3.17 (ENCB), J14.1
/sheet6190D04B/ENCN: A3.20 (ENCN), J14.3
/sheet6190D04B/S2_1A: A3.13 (1A), J10.4
/sheet6190D04B/S2_1B: A3.12 (1B), J10.2
/sheet6190D04B/S2_2A: A3.14 (2A), J10.3
/sheet6190D04B/S2_2B: A3.11 (2B), J10.1
GND: A2.9 (GND), A2.15 (GND), A3.9 (GND), A3.15 (GND), C2.2, C3.2, J12.4, J14.4; also elsewhere on the board

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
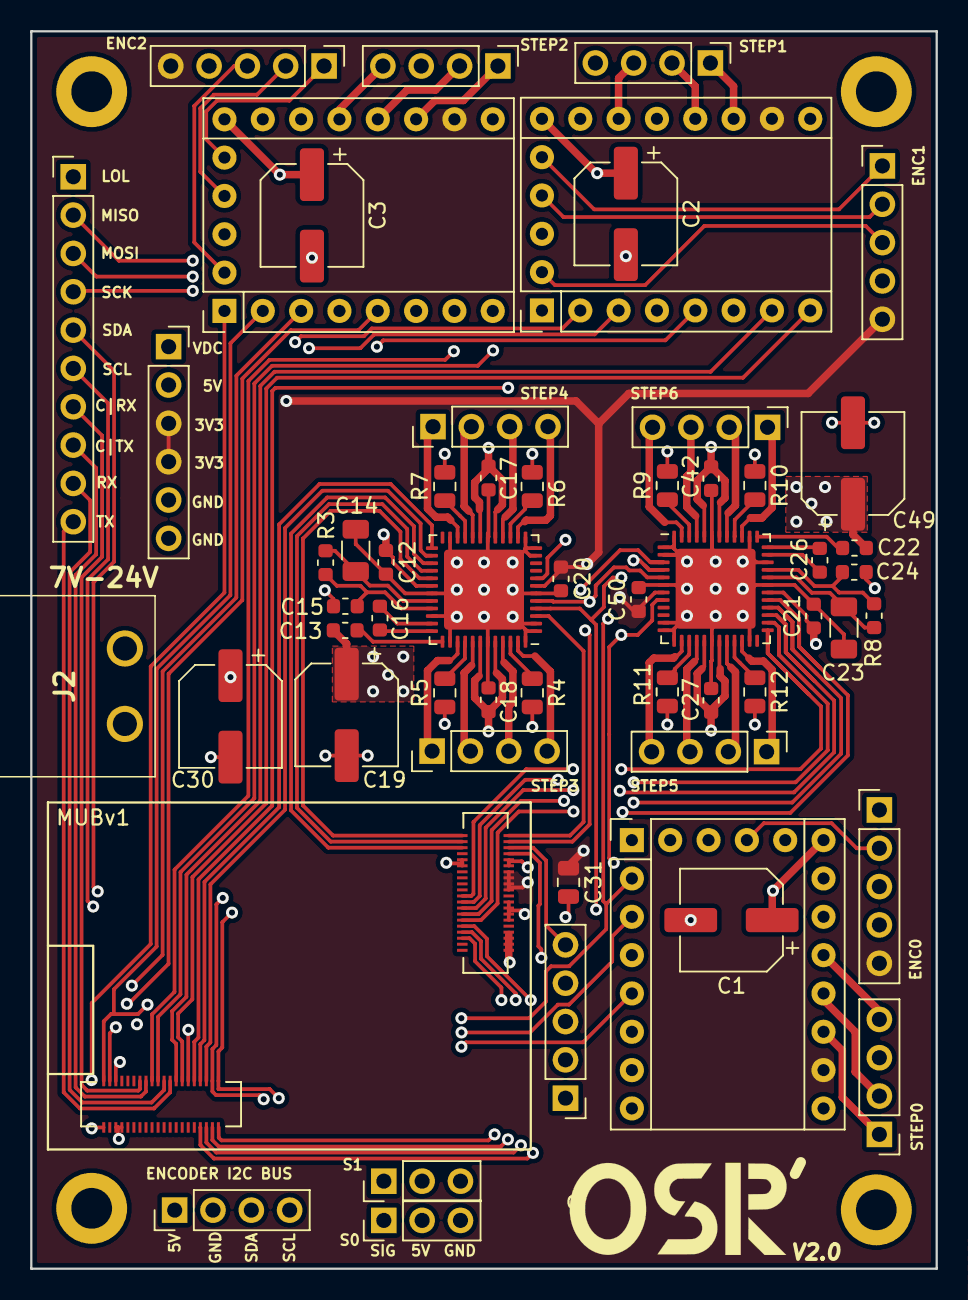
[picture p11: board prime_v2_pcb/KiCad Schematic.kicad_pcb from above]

Board: 4 copper layers, 60.0 x 82.0 mm, 60 parts (0 on the bottom side), 95 nets.

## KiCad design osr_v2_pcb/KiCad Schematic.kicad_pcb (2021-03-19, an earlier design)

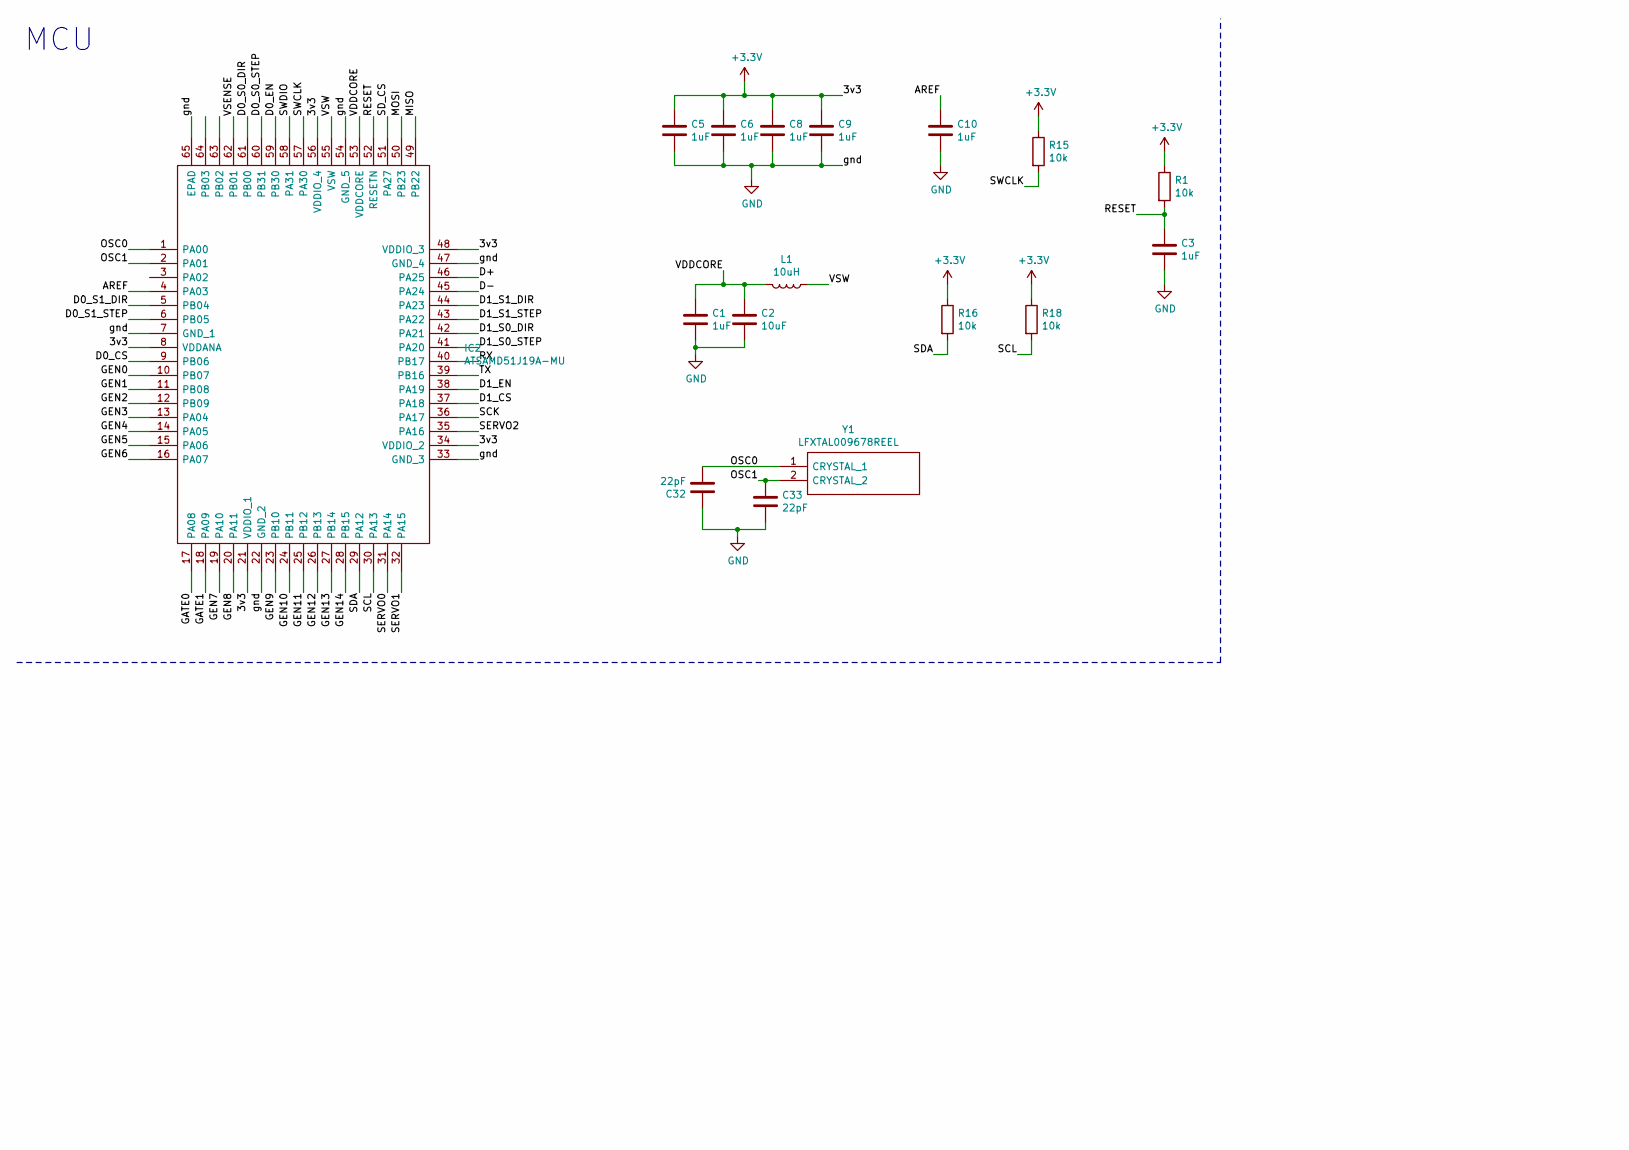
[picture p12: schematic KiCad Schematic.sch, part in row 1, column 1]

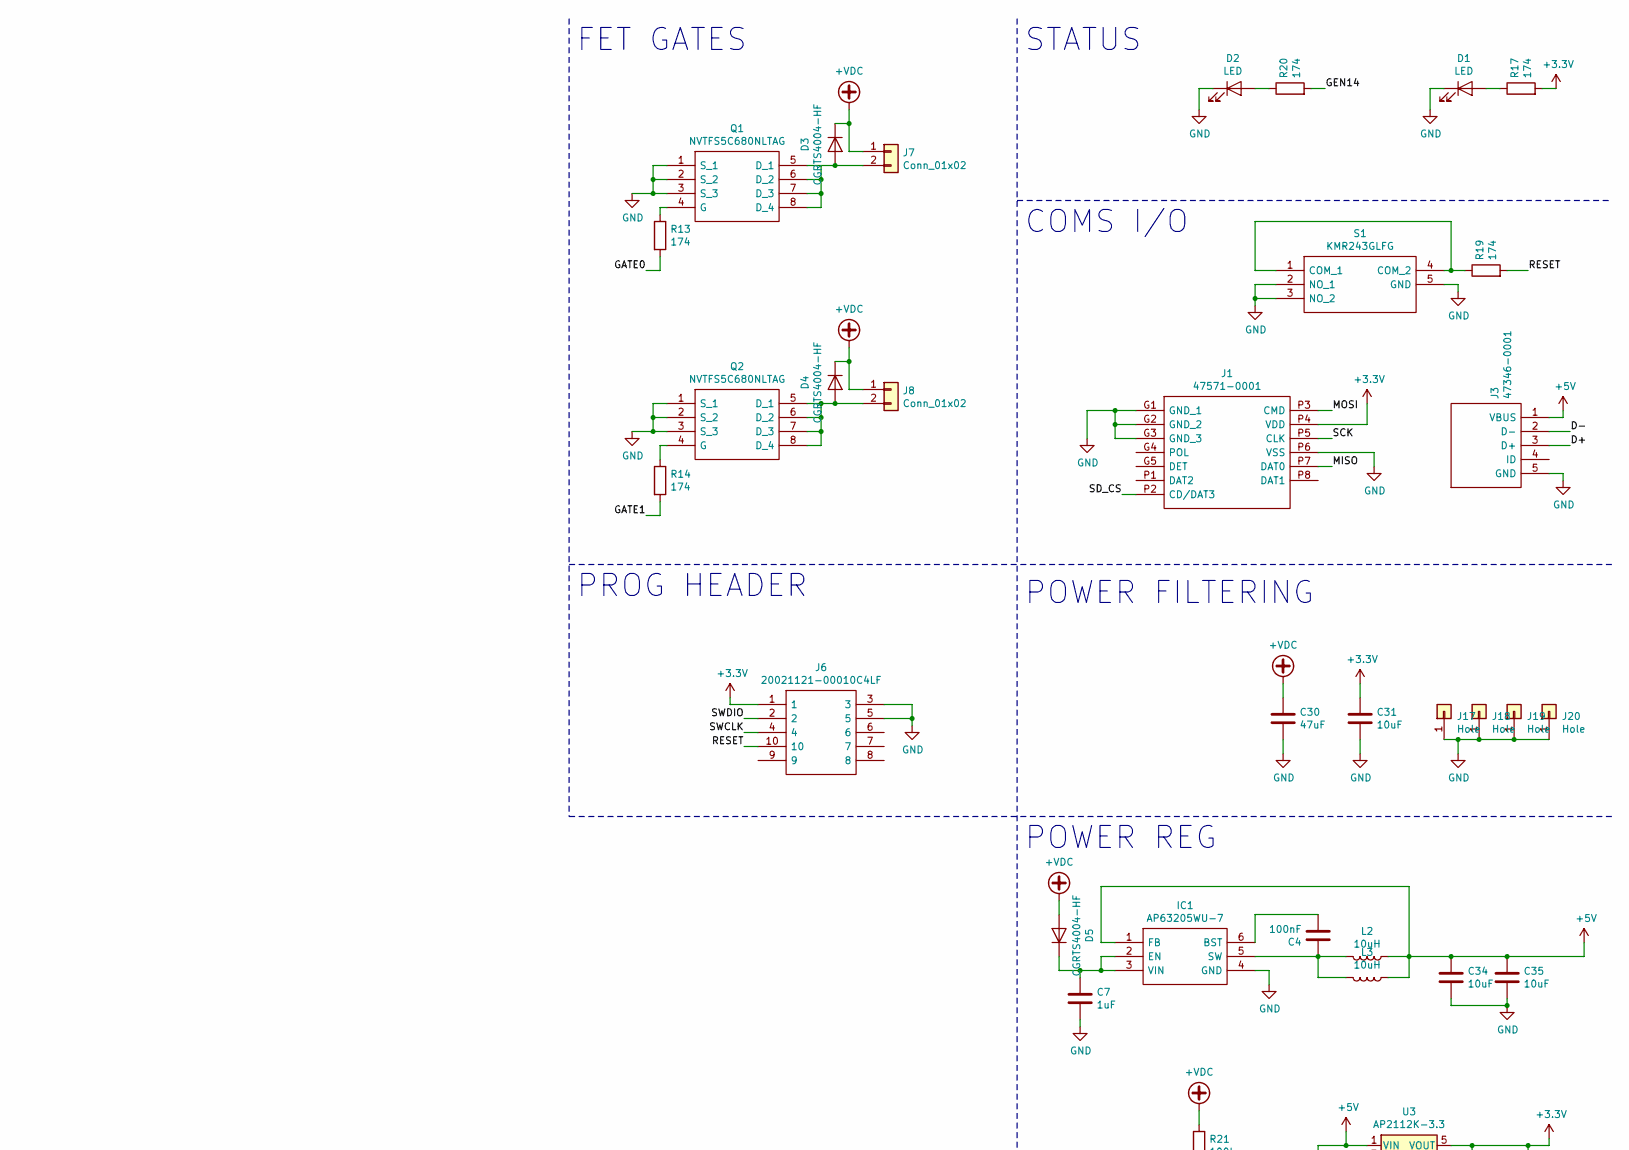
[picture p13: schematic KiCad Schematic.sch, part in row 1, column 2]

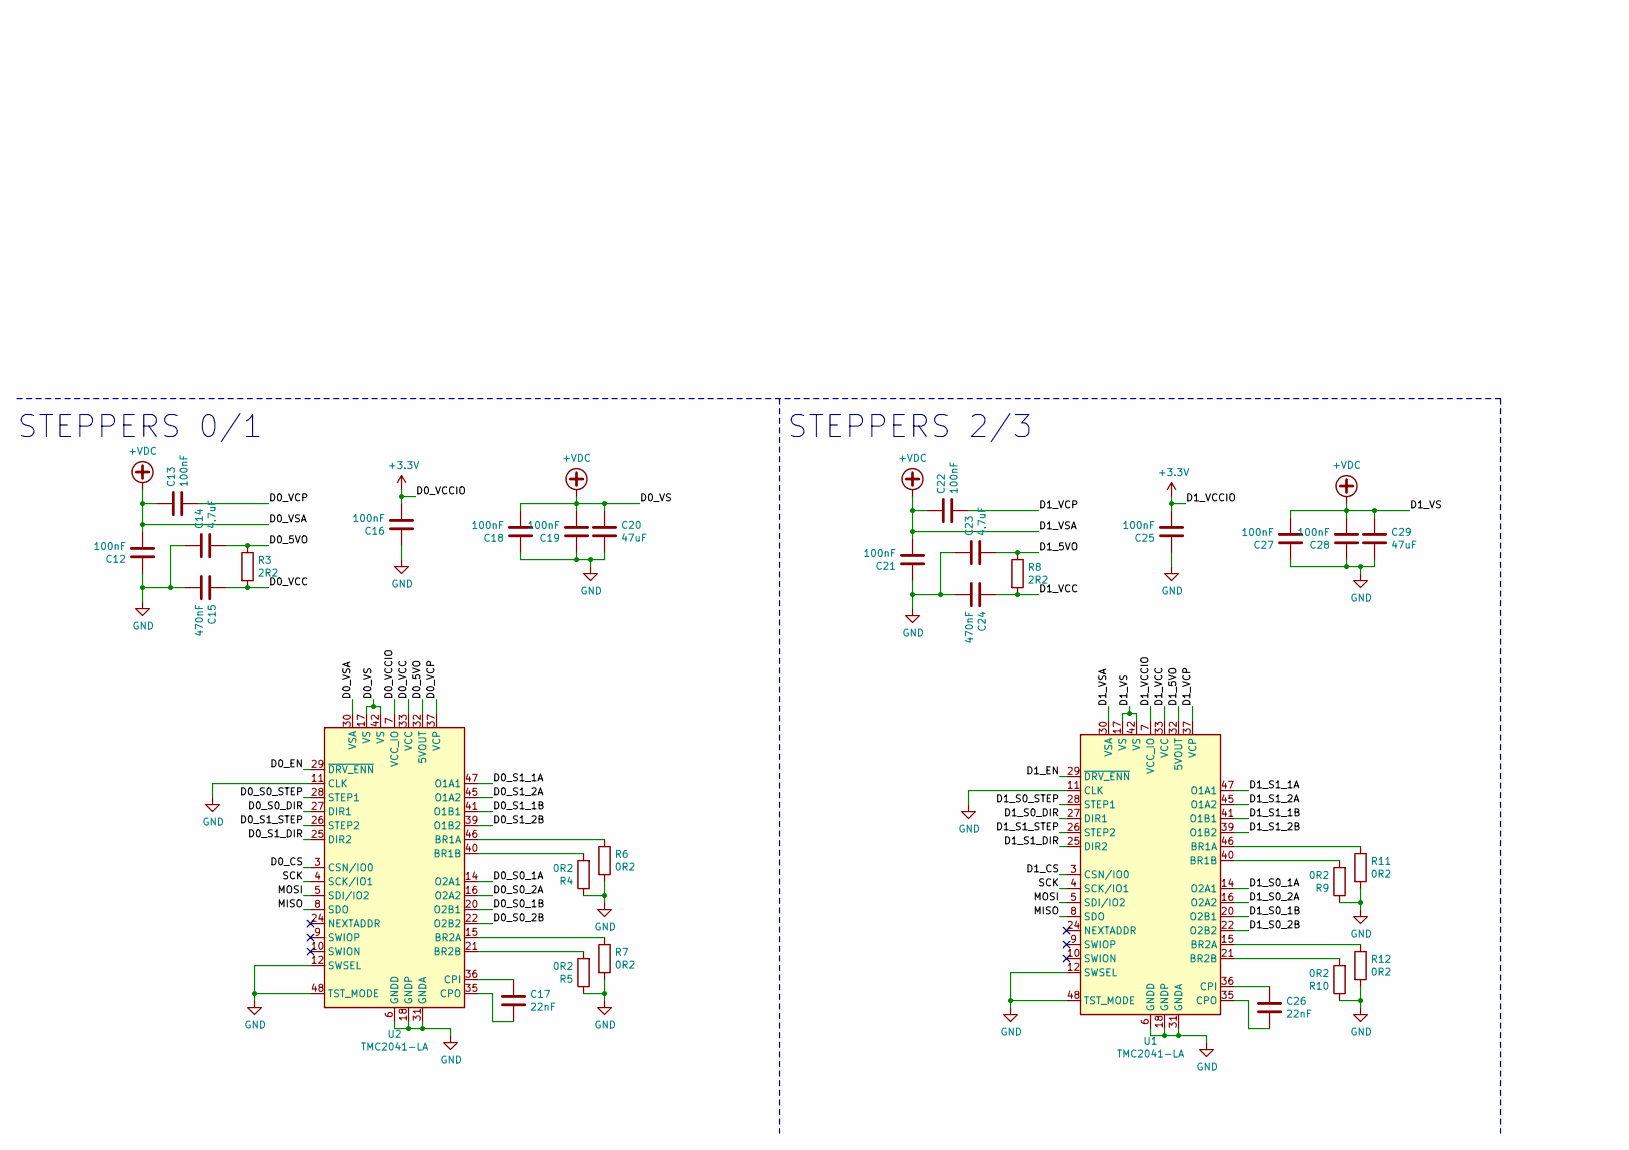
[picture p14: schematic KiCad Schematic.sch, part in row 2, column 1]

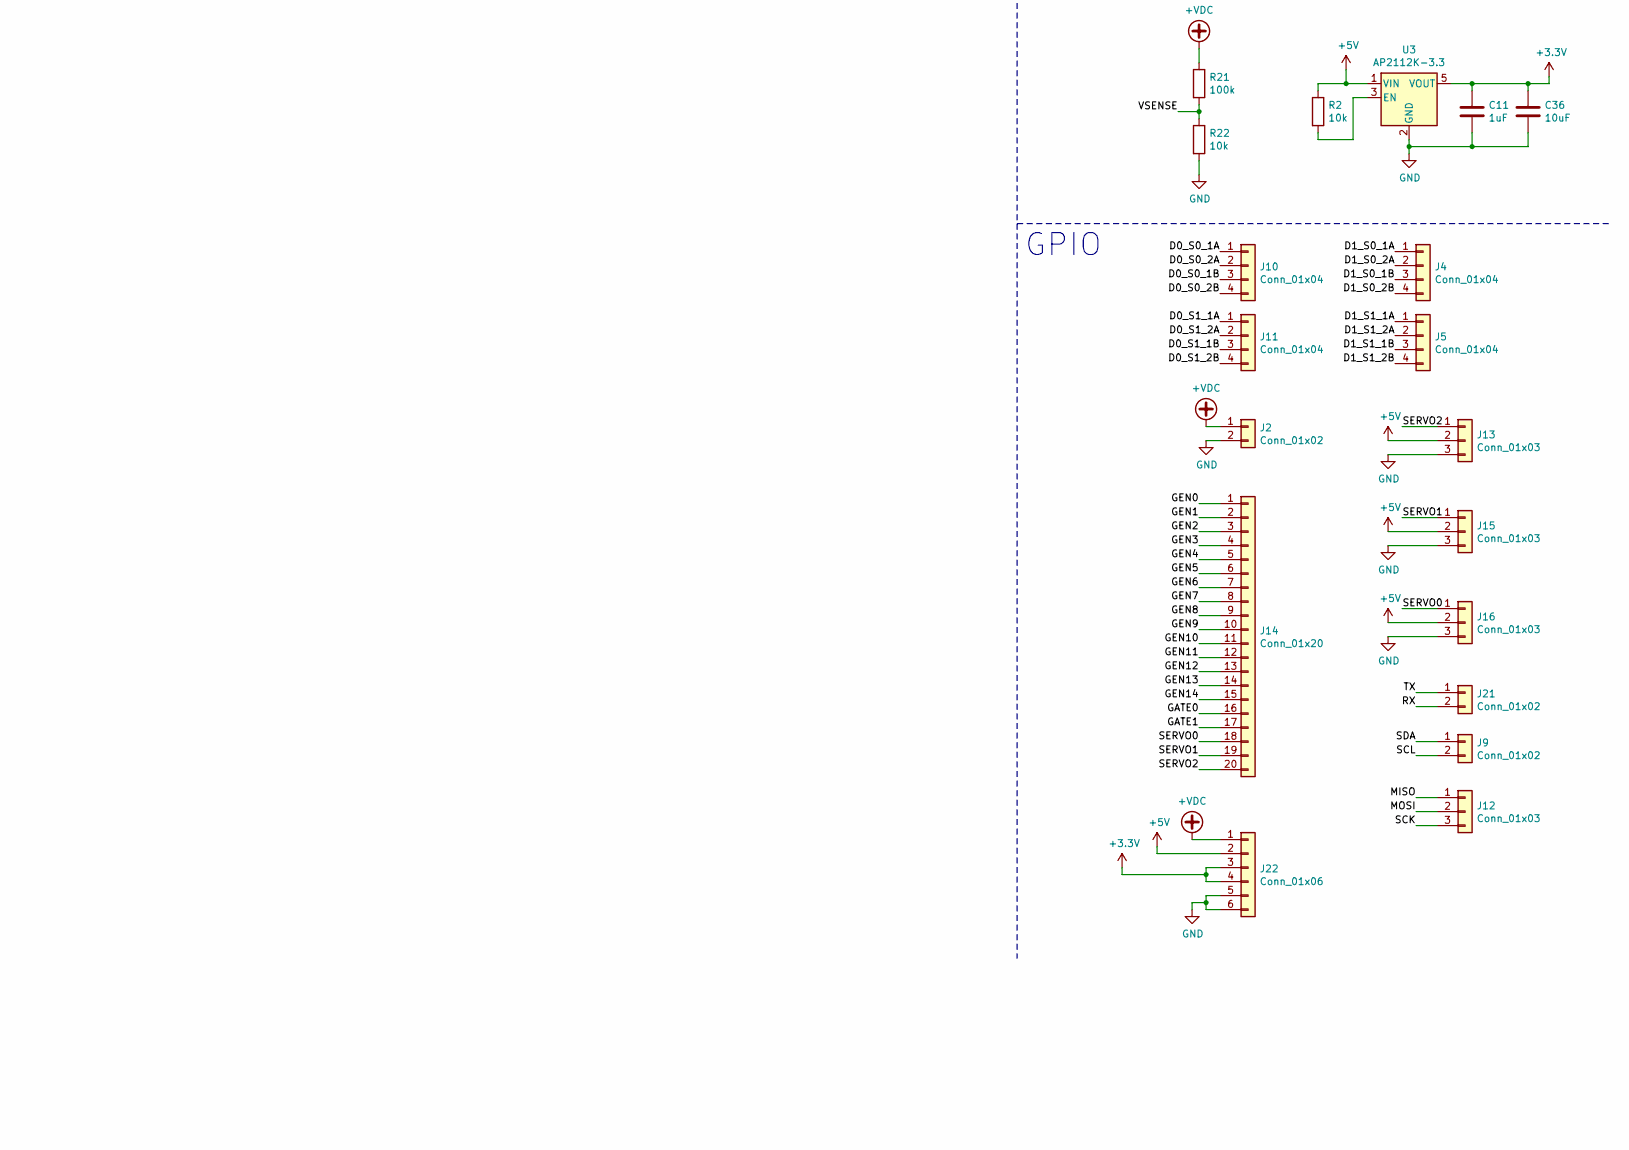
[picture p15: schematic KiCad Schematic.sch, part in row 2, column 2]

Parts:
C1, C3, C5, C6, C7, C8, C9, C10, C11: 1uF; C_0603_1608Metric
C2, C31, C34, C35, C36: 10uF; C_0805_2012Metric
C4, C12, C13, C16, C18, C19, C21, C22, C25, C27, C28: 100nF; C_0603_1608Metric
C14, C23: 4.7uF; C_1206_3216Metric
C15, C24: 470nF; C_0603_1608Metric
C17, C26: 22nF; C_0603_1608Metric
C20, C29, C30: 47uF; CP_Elec_6.3x7.7
C32, C33: 22pF; C_0603_1608Metric
D1, D2: LED; LED_0603_1608Metric
D3, D4, D5: CGRTS4004-HF; D_SOD-123F
IC1: AP63205WU-7; SOT95P280X100-6N; Mouser Part Number 621-AP63205WU-7
IC2: ATSAMD51J19A-MU; QFN-64-1EP_9x9mm_P0.5mm_EP6x6mm_ThermalVias; Mouser Part Number 556-ATSAMD51J19AMU
J1: 47571-0001; 475710001; Mouser Part Number 538-47571-0001
J2: Conn_01x02; BarrelJack_Wuerth_6941xx301002
J3: 47346-0001; Mouser Part Number 538-47346-0001
J4, J5, J10, J11: Conn_01x04; PinHeader_1x04_P2.54mm_Vertical
J6: 20021121-00010C4LF; 2002112100010C4LF; Mouser Part Number 649-202112100010C4LF
J7, J8, J9, J21: Conn_01x02; PinHeader_1x02_P2.54mm_Vertical
J12, J13, J15, J16: Conn_01x03; PinHeader_1x03_P2.54mm_Vertical
J14: Conn_01x20; PinSocket_1x20_P2.54mm_Vertical
J17, J18, J19, J20: Hole; MountingHole_2.7mm_M2.5_DIN965_Pad
J22: Conn_01x06; PinSocket_1x06_P2.54mm_Vertical
L1, L2, L3: 10uH; L_0805_2012Metric
Q1, Q2: NVTFS5C680NLTAG; NVTFS6H854NTAG; Mouser Part Number 863-NVTFS5C680NLTAG
R1, R2, R15, R16, R18, R22: 10k; R_0603_1608Metric
R3, R8: 2R2; R_0603_1608Metric
R4, R5, R6, R7, R9, R10, R11, R12: 0R2; R_0805_2012Metric
R13, R14, R17, R19, R20: 174; R_0603_1608Metric
R21: 100k; R_0603_1608Metric
S1: KMR243GLFG; KMR421GULCLFS; Mouser Part Number 611-KMR243GLFG
U1, U2: TMC2041-LA; QFN-48-1EP_7x7mm_P0.5mm_EP5.3x5.3mm_ThermalVias
U3: AP2112K-3.3; SOT-23-5
Y1: LFXTAL009678REEL; Mouser Part Number 449-LFXTAL009678REEL

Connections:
+3V3: C5.1, C6.1, C8.1, C9.1, C11.1, C16.2, C25.2, C31.1, C36.1, IC2.8 (VDDANA), IC2.21 (VDDIO_1), IC2.34 (VDDIO_2), IC2.48 (VDDIO_3), IC2.56 (VDDIO_4), J1.P4 (VDD), J6.1, J22.3, J22.4, R1.1, R15.1, R16.1, R17.2, R18.1, U1.7 (VCC_IO), U2.7 (VCC_IO), U3.5 (VOUT)
+5V: C34.1, C35.1, IC1.1 (FB), J3.1 (VBUS), J13.2, J15.2, J16.2, J22.2, L2.1, L3.1, R2.1, U3.1 (VIN)
+VDC: C12.2, C13.1, C18.2, C19.2, C20.1, C21.2, C22.1, C27.2, C28.2, C29.1, C30.1, D3.1 (K), D4.1 (K), D5.2 (A), J2.1, J7.1, J8.1, J22.1, R21.1, U1.17 (VS), U1.19 (VS), U1.30 (VSA), U1.42 (VS), U1.44 (VS), U2.17 (VS), U2.19 (VS), U2.30 (VSA), U2.42 (VS), U2.44 (VS)
/AREF: C10.1, IC2.4 (PA03)
/D0_5VO: C14.2, R3.1, U2.32 (5VOUT)
/D0_CS: IC2.9 (PB06), U2.3 (CSN/IO0)
/D0_EN: IC2.59 (PB30), U2.29 (~DRV_ENN)
/D0_S0_1A: J10.1, U2.14 (O2A1)
/D0_S0_1B: J10.3, U2.20 (O2B1)
/D0_S0_2A: J10.2, U2.16 (O2A2)
/D0_S0_2B: J10.4, U2.22 (O2B2)
/D0_S0_DIR: IC2.61 (PB00), U2.27 (DIR1)
/D0_S0_STEP: IC2.60 (PB31), U2.28 (STEP1)
/D0_S1_1A: J11.1, U2.47 (O1A1)
/D0_S1_1B: J11.3, U2.41 (O1B1)
/D0_S1_2A: J11.2, U2.45 (O1A2)
/D0_S1_2B: J11.4, U2.39 (O1B2)
/D0_S1_DIR: IC2.5 (PB04), U2.25 (DIR2)
/D0_S1_STEP: IC2.6 (PB05), U2.26 (STEP2)
/D0_VCC: C15.1, R3.2, U2.33 (VCC)
/D0_VCP: C13.2, U2.37 (VCP)
/D1_5VO: C23.2, R8.1, U1.32 (5VOUT)
/D1_CS: IC2.37 (PA18), U1.3 (CSN/IO0)
/D1_EN: IC2.38 (PA19), U1.29 (~DRV_ENN)
/D1_S0_1A: J4.1, U1.14 (O2A1)
/D1_S0_1B: J4.3, U1.20 (O2B1)
/D1_S0_2A: J4.2, U1.16 (O2A2)
/D1_S0_2B: J4.4, U1.22 (O2B2)
/D1_S0_DIR: IC2.42 (PA21), U1.27 (DIR1)
/D1_S0_STEP: IC2.41 (PA20), U1.28 (STEP1)
/D1_S1_1A: J5.1, U1.47 (O1A1)
/D1_S1_1B: J5.3, U1.41 (O1B1)
/D1_S1_2A: J5.2, U1.45 (O1A2)
/D1_S1_2B: J5.4, U1.39 (O1B2)
/D1_S1_DIR: IC2.44 (PA23), U1.25 (DIR2)
/D1_S1_STEP: IC2.43 (PA22), U1.26 (STEP2)
/D1_VCC: C24.1, R8.2, U1.33 (VCC)
/D1_VCP: C22.2, U1.37 (VCP)
/D+: IC2.46 (PA25), J3.3 (D+)
/D-: IC2.45 (PA24), J3.2 (D-)
/GATE0: IC2.17 (PA08), J14.16, R13.2
/GATE1: IC2.18 (PA09), J14.17, R14.2
/GEN0: IC2.10 (PB07), J14.1
/GEN1: IC2.11 (PB08), J14.2
/GEN2: IC2.12 (PB09), J14.3
/GEN3: IC2.13 (PA04), J14.4
/GEN4: IC2.14 (PA05), J14.5
/GEN5: IC2.15 (PA06), J14.6
/GEN6: IC2.16 (PA07), J14.7
/GEN7: IC2.19 (PA10), J14.8
/GEN8: IC2.20 (PA11), J14.9
/GEN9: IC2.23 (PB10), J14.10
/GEN10: IC2.24 (PB11), J14.11
/GEN11: IC2.25 (PB12), J14.12
/GEN12: IC2.26 (PB13), J14.13
/GEN13: IC2.27 (PB14), J14.14
/GEN14: IC2.28 (PB15), J14.15, R20.2
/MISO: IC2.49 (PB22), J1.P7 (DAT0), J12.1, U1.8 (SDO), U2.8 (SDO)
/MOSI: IC2.50 (PB23), J1.P3 (CMD), J12.2, U1.5 (SDI/IO2), U2.5 (SDI/IO2)
/OSC0: C32.2, IC2.1 (PA00), Y1.1 (CRYSTAL_1)
/OSC1: C33.1, IC2.2 (PA01), Y1.2 (CRYSTAL_2)
/RESET: C3.1, IC2.52 (RESETN), J6.10, R1.2, R19.2
/RX: IC2.40 (PB17), J21.2
/SCK: IC2.36 (PA17), J1.P5 (CLK), J12.3, U1.4 (SCK/IO1), U2.4 (SCK/IO1)
/SCL: IC2.30 (PA13), J9.2, R18.2
/SDA: IC2.29 (PA12), J9.1, R16.2
/SD_CS: IC2.51 (PA27), J1.P2 (CD/DAT3)
/SERVO0: IC2.31 (PA14), J14.18, J16.1
/SERVO1: IC2.32 (PA15), J14.19, J15.1
/SERVO2: IC2.35 (PA16), J13.1, J14.20
/SWCLK: IC2.57 (PA30), J6.4, R15.2
/SWDIO: IC2.58 (PA31), J6.2
/TX: IC2.39 (PB16), J21.1
/VDDCORE: C1.1, C2.1, IC2.53 (VDDCORE), L1.2
/VSENSE: IC2.62 (PB01), R21.2, R22.1
/VSW: IC2.55 (VSW), L1.1
GND: C1.2, C2.2, C3.2, C5.2, C6.2, C7.2, C8.2, C9.2, C10.2, C11.2, C12.1, C14.1, C15.2, C16.1, C18.1, C19.1, C20.2, C21.1, C23.1, C24.2, C25.1, C27.1, C28.1, C29.2, C30.2, C31.2, C32.1, C33.2, C34.2, C35.2, C36.2, D1.1 (K), D2.1 (K), IC1.4 (GND), IC2.7 (GND_1), IC2.22 (GND_2), IC2.33 (GND_3), IC2.47 (GND_4), IC2.54 (GND_5), IC2.65 (EPAD), J1.G1 (GND_1), J1.G2 (GND_2), J1.G3 (GND_3), J1.P6 (VSS), J2.2, J3.5 (GND), J6.3, J6.5, J13.3, J15.3, J16.3, J17.1, J18.1, J19.1, J20.1, J22.5, J22.6, Q1.1 (S_1), Q1.2 (S_2), Q1.3 (S_3), Q2.1 (S_1), Q2.2 (S_2), Q2.3 (S_3), R4.1, R5.1, R6.2, R7.2, R9.1, R10.1, R11.2, R12.2, R22.2, S1.2 (NO_1), S1.3 (NO_2), S1.5 (GND), U1.1 (GNDD), U1.2 (GNDD), U1.6 (GNDD), U1.11 (CLK), U1.12 (SWSEL), U1.13 (GNDD), U1.18 (GNDP), U1.23 (GNDD), U1.31 (GNDA), U1.34 (GNDD), U1.38 (GNDD), U1.43 (GNDP), U1.48 (TST_MODE), U1.49 (GNDD), U2.1 (GNDD), U2.2 (GNDD), U2.6 (GNDD), U2.11 (CLK), U2.12 (SWSEL), U2.13 (GNDD), U2.18 (GNDP), U2.23 (GNDD), U2.31 (GNDA), U2.34 (GNDD), U2.38 (GNDD), U2.43 (GNDP), U2.48 (TST_MODE), U2.49 (GNDD), U3.2 (GND)
unnamed: C4.1, IC1.5 (SW), L2.2, L3.2
unnamed: C4.2, IC1.6 (BST)
unnamed: C7.1, D5.1 (K), IC1.2 (EN), IC1.3 (VIN)
unnamed: C17.1, U2.36 (CPI)
unnamed: C17.2, U2.35 (CPO)
unnamed: C26.1, U1.36 (CPI)
unnamed: C26.2, U1.35 (CPO)
unnamed: D1.2 (A), R17.1
unnamed: D2.2 (A), R20.1
unnamed: D3.2 (A), J7.2, Q1.5 (D_1), Q1.6 (D_2), Q1.7 (D_3), Q1.8 (D_4)
unnamed: D4.2 (A), J8.2, Q2.5 (D_1), Q2.6 (D_2), Q2.7 (D_3), Q2.8 (D_4)
unnamed: Q1.4 (G), R13.1
unnamed: Q2.4 (G), R14.1
unnamed: R2.2, U3.3 (EN)
unnamed: R4.2, U2.40 (BR1B)
unnamed: R5.2, U2.21 (BR2B)
unnamed: R6.1, U2.46 (BR1A)
unnamed: R7.1, U2.15 (BR2A)
unnamed: R9.2, U1.40 (BR1B)
unnamed: R10.2, U1.21 (BR2B)
unnamed: R11.1, U1.46 (BR1A)
unnamed: R12.1, U1.15 (BR2A)
unnamed: R19.1, S1.1 (COM_1), S1.4 (COM_2)

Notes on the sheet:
GPIO
POWER REG
POWER FILTERING
STEPPERS 0/1
STEPPERS 2/3
COMS I/O
STATUS
FET GATES
PROG HEADER
MCU

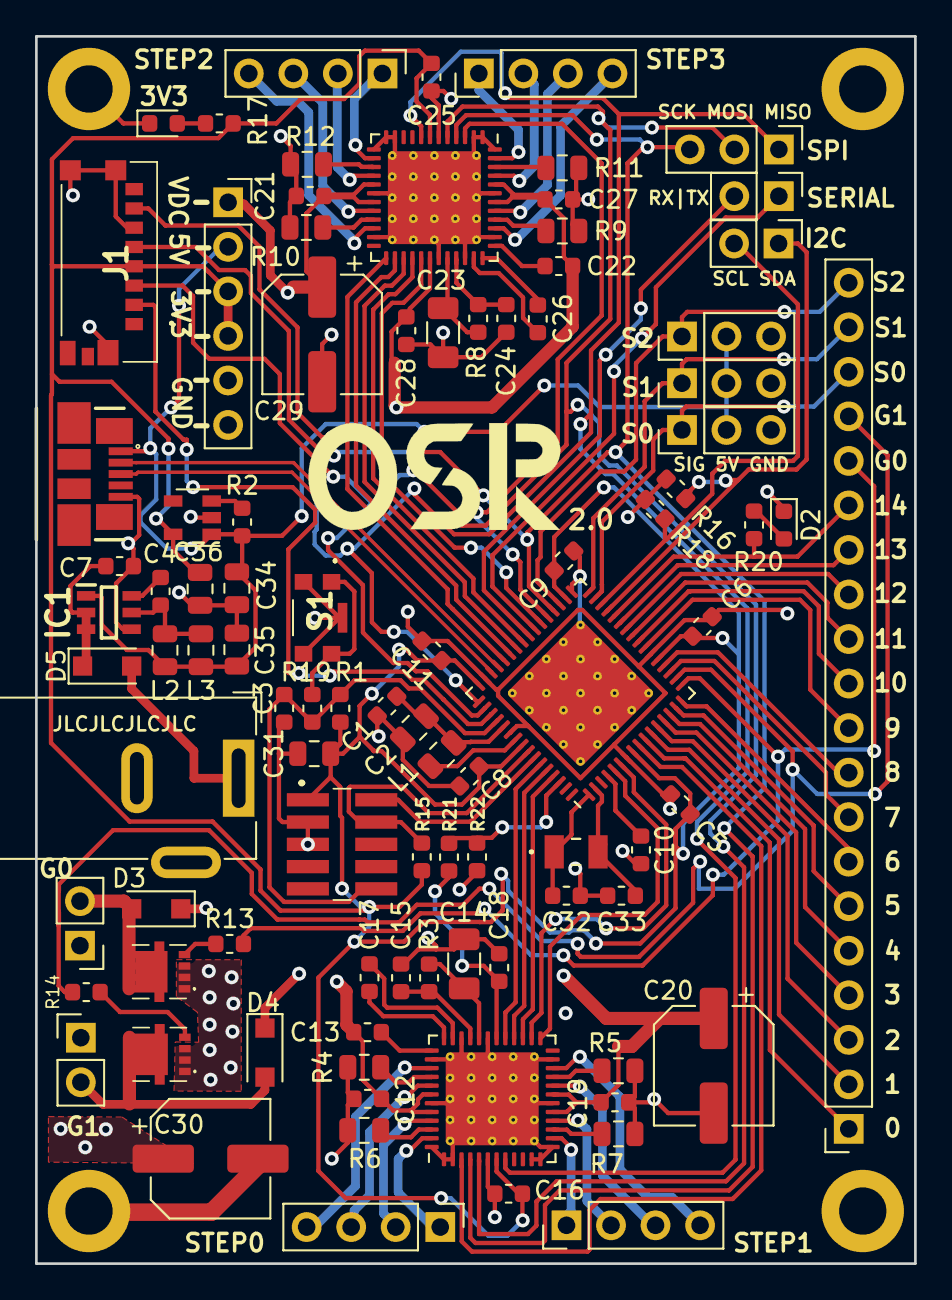
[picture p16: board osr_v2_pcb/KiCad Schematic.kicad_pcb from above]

Board: 2 copper layers, 50.1 x 70.0 mm, 97 parts (0 on the bottom side), 100 nets.

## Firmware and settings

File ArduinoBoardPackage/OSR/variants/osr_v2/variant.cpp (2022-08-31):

/*
  Copyright (c) 2014-2015 Arduino LLC.  All right reserved.

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
  You should have received a copy of the GNU Lesser General Public
  License along with this library; if not, write to the Free Software
  Foundation, Inc., 51 Franklin St, Fifth Floor, Boston, MA  02110-1301  USA
*/

#include "variant.h"

/*
 * Pins descriptions
 */

//TCC0 IOSET 6
//TCC1 IOSET 1
//TC0 IOSET 1
//TC1 IOSET 1
//TC2 IOSET 2
//TC3 IOSET 1
//TC4 IOSET 1
const PinDescription g_APinDescription[]=
{
  // 0..6 - Analog Pins
  { PORTB,  7, PIO_ANALOG, (PIN_ATTR_ANALOG|PIN_ATTR_PWM_E), ADC_Channel9, NOT_ON_PWM, NOT_ON_TIMER, EXTERNAL_INT_NONE },
  { PORTB,  8, PIO_ANALOG, (PIN_ATTR_ANALOG|PIN_ATTR_PWM_E), ADC_Channel0, TC4_CH0, TC4_CH0, EXTERNAL_INT_NONE },
  { PORTB,  9, PIO_ANALOG, (PIN_ATTR_ANALOG|PIN_ATTR_PWM_E), ADC_Channel3, TC4_CH1, TC4_CH1, EXTERNAL_INT_9 },
  { PORTA,  4, PIO_ANALOG, (PIN_ATTR_ANALOG|PIN_ATTR_PWM_E), ADC_Channel4, TC0_CH0, TC0_CH0, EXTERNAL_INT_4 },
  { PORTA,  5, PIO_ANALOG, (PIN_ATTR_ANALOG|PIN_ATTR_PWM_E), ADC_Channel5, TC0_CH1, TC0_CH1, EXTERNAL_INT_5 },
  { PORTA,  6, PIO_ANALOG, (PIN_ATTR_ANALOG|PIN_ATTR_PWM_E), ADC_Channel6, TC1_CH0, TC1_CH0, EXTERNAL_INT_6 },
  { PORTA,  7, PIO_ANALOG, (PIN_ATTR_ANALOG|PIN_ATTR_PWM_E), ADC_Channel7, TC1_CH1, TC1_CH1, EXTERNAL_INT_7 },

  // 7..14 - Digital Pins
  { PORTA, 10, PIO_DIGITAL, PIN_ATTR_NONE, No_ADC_Channel, NOT_ON_PWM, NOT_ON_TIMER, EXTERNAL_INT_NONE },
  { PORTA, 11, PIO_DIGITAL, PIN_ATTR_NONE, No_ADC_Channel, NOT_ON_PWM, NOT_ON_TIMER, EXTERNAL_INT_NONE },
  { PORTB, 10, PIO_DIGITAL, PIN_ATTR_NONE, No_ADC_Channel, NOT_ON_PWM, NOT_ON_TIMER, EXTERNAL_INT_10 },
  { PORTB, 11, PIO_DIGITAL, PIN_ATTR_NONE, No_ADC_Channel, NOT_ON_PWM, NOT_ON_TIMER, EXTERNAL_INT_11 },
  { PORTB, 12, PIO_DIGITAL, PIN_ATTR_NONE, No_ADC_Channel, NOT_ON_PWM, NOT_ON_TIMER, EXTERNAL_INT_12 },
  { PORTB, 13, PIO_DIGITAL, PIN_ATTR_NONE, No_ADC_Channel, NOT_ON_PWM, NOT_ON_TIMER, EXTERNAL_INT_13 },
  { PORTB, 14, PIO_DIGITAL, PIN_ATTR_NONE, No_ADC_Channel, NOT_ON_PWM, NOT_ON_TIMER, EXTERNAL_INT_14 },
  { PORTB, 15, PIO_DIGITAL, PIN_ATTR_NONE, No_ADC_Channel, NOT_ON_PWM, NOT_ON_TIMER, EXTERNAL_INT_15 },

  // 15..16 - SERCOM/UART (Serial1)
  { PORTB, 17, PIO_SERCOM, PIN_ATTR_PWM_G, No_ADC_Channel, TCC0_CH4, NOT_ON_TIMER, EXTERNAL_INT_1 }, // RX: SERCOM5/PAD[1]
  { PORTB, 16, PIO_SERCOM, PIN_ATTR_PWM_G, No_ADC_Channel, TCC0_CH5, NOT_ON_TIMER, EXTERNAL_INT_0 }, // TX: SERCOM5/PAD[0]

  // 17..18 - Gates
  { PORTA,  8, PIO_DIGITAL, PIN_ATTR_PWM_E, No_ADC_Channel, TCC0_CH0, NOT_ON_TIMER, EXTERNAL_INT_NONE },
  { PORTA,  9, PIO_DIGITAL, PIN_ATTR_PWM_E, No_ADC_Channel, TCC0_CH1, NOT_ON_TIMER, EXTERNAL_INT_NONE },

  // 19..20 - I2C pins (SDA/SCL)
  { PORTA, 12, PIO_SERCOM, PIN_ATTR_PWM_E, No_ADC_Channel, TC2_CH0, TC2_CH0, EXTERNAL_INT_12 }, // SDA: SERCOM2/PAD[0]
  { PORTA, 13, PIO_SERCOM, PIN_ATTR_PWM_E, No_ADC_Channel, TC2_CH1, TC2_CH1, EXTERNAL_INT_13 }, // SCL: SERCOM2/PAD[1]

  // 21..23 - SPI pins (MISO,MOSI,SCK)
  { PORTB, 22, PIO_SERCOM, PIN_ATTR_DIGITAL, No_ADC_Channel, NOT_ON_PWM, NOT_ON_TIMER, EXTERNAL_INT_6 }, // MISO: SERCOM1/PAD[2]
  { PORTB, 23, PIO_SERCOM, PIN_ATTR_DIGITAL, No_ADC_Channel, NOT_ON_PWM, NOT_ON_TIMER, EXTERNAL_INT_7 }, // MOSI: SERCOM1/PAD[3]
  { PORTA, 17, PIO_SERCOM, PIN_ATTR_DIGITAL, No_ADC_Channel, NOT_ON_PWM, NOT_ON_TIMER, EXTERNAL_INT_1 }, // SCK: SERCOM1/PAD[1]

  // 24..26 - USB
  { NOT_A_PORT, 0, PIO_NOT_A_PIN, PIN_ATTR_NONE, No_ADC_Channel, NOT_ON_PWM, NOT_ON_TIMER, EXTERNAL_INT_NONE }, // USB Host enable DOES NOT EXIST ON THIS BOARD
  { PORTA, 24, PIO_COM, PIN_ATTR_NONE, No_ADC_Channel, NOT_ON_PWM, NOT_ON_TIMER, EXTERNAL_INT_NONE }, // USB/DM
  { PORTA, 27, PIO_COM, PIN_ATTR_NONE, No_ADC_Channel, NOT_ON_PWM, NOT_ON_TIMER, EXTERNAL_INT_NONE }, // USB/DP

  // 27 - AREF
  { PORTA, 3, PIO_ANALOG, PIN_ATTR_ANALOG, No_ADC_Channel, NOT_ON_PWM, NOT_ON_TIMER, EXTERNAL_INT_NONE }, // DAC/VREFP

  // 28..33 - Stepper driver 0 pins
  { PORTB,  6, PIO_DIGITAL, PIN_ATTR_NONE, No_ADC_Channel, NOT_ON_PWM, NOT_ON_TIMER, EXTERNAL_INT_NONE },   // D0_CS
  { PORTB, 30, PIO_DIGITAL, PIN_ATTR_NONE, No_ADC_Channel, NOT_ON_PWM, NOT_ON_TIMER, EXTERNAL_INT_NONE },   // D0_EN
  { PORTB, 31, PIO_DIGITAL, PIN_ATTR_NONE, No_ADC_Channel, NOT_ON_PWM, NOT_ON_TIMER, EXTERNAL_INT_NONE },   // D0_S0_STEP
  { PORTB,  0, PIO_DIGITAL, PIN_ATTR_NONE, No_ADC_Channel, NOT_ON_PWM, NOT_ON_TIMER, EXTERNAL_INT_NONE },   // D0_S0_DIR
  { PORTB,  5, PIO_DIGITAL, PIN_ATTR_NONE, No_ADC_Channel, NOT_ON_PWM, NOT_ON_TIMER, EXTERNAL_INT_NONE },   // D0_S1_STEP
  { PORTB,  4, PIO_DIGITAL, PIN_ATTR_NONE, No_ADC_Channel, NOT_ON_PWM, NOT_ON_TIMER, EXTERNAL_INT_NONE },   // D0_S1_DIR

  // 34..39 - Stepper driver 1 pins
  { PORTA, 18, PIO_DIGITAL, PIN_ATTR_NONE, No_ADC_Channel, NOT_ON_PWM, NOT_ON_TIMER, EXTERNAL_INT_NONE },   // D1_CS
  { PORTA, 19, PIO_DIGITAL, PIN_ATTR_NONE, No_ADC_Channel, NOT_ON_PWM, NOT_ON_TIMER, EXTERNAL_INT_NONE },   // D1_EN
  { PORTA, 20, PIO_DIGITAL, PIN_ATTR_NONE, No_ADC_Channel, NOT_ON_PWM, NOT_ON_TIMER, EXTERNAL_INT_NONE },   // D1_S0_STEP
  { PORTA, 21, PIO_DIGITAL, PIN_ATTR_NONE, No_ADC_Channel, NOT_ON_PWM, NOT_ON_TIMER, EXTERNAL_INT_NONE },   // D1_S0_DIR
  { PORTA, 22, PIO_DIGITAL, PIN_ATTR_NONE, No_ADC_Channel, NOT_ON_PWM, NOT_ON_TIMER, EXTERNAL_INT_NONE },   // D1_S1_STEP
  { PORTA, 23, PIO_DIGITAL, PIN_ATTR_NONE, No_ADC_Channel, NOT_ON_PWM, NOT_ON_TIMER, EXTERNAL_INT_NONE },   // D1_S1_DIR

  // 40 - SD Chip Select
  { PORTA, 27,  PIO_DIGITAL, PIN_ATTR_NONE, No_ADC_Channel, NOT_ON_PWM, NOT_ON_TIMER, EXTERNAL_INT_NONE }, // CS

  // 41..43 - Servo Pins
  { PORTA, 14, PIO_DIGITAL, PIN_ATTR_NONE, No_ADC_Channel, NOT_ON_PWM, NOT_ON_TIMER, EXTERNAL_INT_NONE },   // Servo0
  { PORTA, 15, PIO_DIGITAL, PIN_ATTR_NONE, No_ADC_Channel, NOT_ON_PWM, NOT_ON_TIMER, EXTERNAL_INT_NONE },   // Servo1
  { PORTA, 16, PIO_DIGITAL, PIN_ATTR_NONE, No_ADC_Channel, NOT_ON_PWM, NOT_ON_TIMER, EXTERNAL_INT_NONE },   // Servo2

  // 44 - VSense
  { PORTB,  1, PIO_DIGITAL, PIN_ATTR_NONE, No_ADC_Channel, NOT_ON_PWM, NOT_ON_TIMER, EXTERNAL_INT_NONE },
} ;

const void* g_apTCInstances[TCC_INST_NUM+TC_INST_NUM]={ TCC0, TCC1, TCC2, TCC3, TCC4, TC0, TC1, TC2, TC3, TC4, TC5 } ;
const uint32_t GCLK_CLKCTRL_IDs[TCC_INST_NUM+TC_INST_NUM] = { TCC0_GCLK_ID, TCC1_GCLK_ID, TCC2_GCLK_ID, TCC3_GCLK_ID, TCC4_GCLK_ID, TC0_GCLK_ID, TC1_GCLK_ID, TC2_GCLK_ID, TC3_GCLK_ID, TC4_GCLK_ID, TC5_GCLK_ID } ;

// Multi-serial objects instantiation
SERCOM sercom0( SERCOM0 ) ;
SERCOM sercom1( SERCOM1 ) ;
SERCOM sercom2( SERCOM2 ) ;
SERCOM sercom3( SERCOM3 ) ;
SERCOM sercom4( SERCOM4 ) ;
SERCOM sercom5( SERCOM5 ) ;

Uart Serial1( &sercom5, PIN_SERIAL1_RX, PIN_SERIAL1_TX, PAD_SERIAL1_RX, PAD_SERIAL1_TX ) ;

void SERCOM5_0_Handler()
{
  Serial1.IrqHandler();
}
void SERCOM5_1_Handler()
{
  Serial1.IrqHandler();
}
void SERCOM5_2_Handler()
{
  Serial1.IrqHandler();
}
void SERCOM5_3_Handler()
{
  Serial1.IrqHandler();
}

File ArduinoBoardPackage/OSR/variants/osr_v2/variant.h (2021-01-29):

/*
  Copyright (c) 2014-2015 Arduino LLC.  All right reserved.

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
  You should have received a copy of the GNU Lesser General Public
  License along with this library; if not, write to the Free Software
  Foundation, Inc., 51 Franklin St, Fifth Floor, Boston, MA  02110-1301  USA
*/

#ifndef _VARIANT_FEATHER_M4_
#define _VARIANT_FEATHER_M4_

// The definitions here needs a SAMD core >=1.6.10
#define ARDUINO_SAMD_VARIANT_COMPLIANCE 10610

/*----------------------------------------------------------------------------
 *        Definitions
 *----------------------------------------------------------------------------*/

/** Frequency of the board main oscillator */
#define VARIANT_MAINOSC		(32768ul)

/** Master clock frequency */
#define VARIANT_MCK        (F_CPU)

#define VARIANT_GCLK0_FREQ (F_CPU)
#define VARIANT_GCLK1_FREQ (48000000UL)
#define VARIANT_GCLK2_FREQ (100000000UL)

/*----------------------------------------------------------------------------
 *        Headers
 *----------------------------------------------------------------------------*/

#include "WVariant.h"

#ifdef __cplusplus
#include "SERCOM.h"
#include "Uart.h"
#endif // __cplusplus

#ifdef __cplusplus
extern "C"
{
#endif // __cplusplus

/*----------------------------------------------------------------------------
 *        Pins
 *----------------------------------------------------------------------------*/

// Number of pins defined in PinDescription array
#define PINS_COUNT           (54u)
#define NUM_DIGITAL_PINS     (35u)
#define NUM_ANALOG_INPUTS    (1u)
#define NUM_ANALOG_OUTPUTS   (1u)
#define analogInputToDigitalPin(p)  ((p < 6u) ? (p) + 14u : -1) // Currently unused

#define digitalPinToPort(P)        ( &(PORT->Group[g_APinDescription[P].ulPort]) )
#define digitalPinToBitMask(P)     ( 1 << g_APinDescription[P].ulPin )
//#define analogInPinToBit(P)        ( )
#define portOutputRegister(port)   ( &(port->OUT.reg) )
#define portInputRegister(port)    ( &(port->IN.reg) )
#define portModeRegister(port)     ( &(port->DIR.reg) )
#define digitalPinHasPWM(P)        ( g_APinDescription[P].ulPWMChannel != NOT_ON_PWM || g_APinDescription[P].ulTCChannel != NOT_ON_TIMER )

/*
 * digitalPinToTimer(..) is AVR-specific and is not defined for SAMD
 * architecture. If you need to check if a pin supports PWM you must
 * use digitalPinHasPWM(..).
 *
 * https://github.com/arduino/Arduino/issues/1833
 */
// #define digitalPinToTimer(P)

// LEDs
#define PIN_LED_14           (14u)
#define PIN_LED              PIN_LED_14
#define LED_BUILTIN          PIN_LED_14


/*
 * Analog pins
 */
#define PIN_A0               (17ul)
#define PIN_A1               (PIN_A0 + 1)

#define PIN_DAC0             PIN_A0
#define PIN_DAC1             PIN_A1

static const uint8_t A0  = PIN_A0;
static const uint8_t A1  = PIN_A1;

static const uint8_t DAC0 = PIN_DAC0;
static const uint8_t DAC1 = PIN_DAC1;

#define ADC_RESOLUTION		12


// Other pins
#define PIN_ATN              (27ul)
static const uint8_t ATN = PIN_ATN;

// Stepper driver pins
#define D0_EN                (29u)
#define D0_S0_STEP           (D0_EN + 1)
#define D0_S0_DIR            (D0_EN + 2)
#define D0_S1_STEP           (D0_EN + 3)
#define D0_S1_DIR            (D0_EN + 4)
#define D1_EN                (35u)
#define D1_S0_STEP           (D1_EN + 1)
#define D1_S0_DIR            (D1_EN + 2)
#define D1_S1_STEP           (D1_EN + 3)
#define D1_S1_DIR            (D1_EN + 4)

static const uint8_t D0EN  = D0_EN ;
static const uint8_t D0S0S = D0_S0_STEP ;
static const uint8_t D0S0D = D0_S0_DIR ;
static const uint8_t D0S1S = D0_S1_STEP ;
static const uint8_t D0S1D = D0_S1_DIR ;
static const uint8_t D1EN  = D1_EN ;
static const uint8_t D1S0S = D1_S0_STEP ;
static const uint8_t D1S0D = D1_S0_DIR ;
static const uint8_t D1S1S = D1_S1_STEP ;
static const uint8_t D1S1D = D1_S1_DIR ;

// Peripheral pins
#define Servo_0              (41u)
#define Servo_1              (Servo_0 + 1)
#define Servo_2              (Servo_0 + 2)
#define Gate_0               (17u)
#define Gate_1               (Gate_0 + 1)
#define VSense               (44u)

static const uint8_t S0 = Servo_0 ;
static const uint8_t S1 = Servo_1 ;
static const uint8_t S2 = Servo_2 ;
static const uint8_t G0 = Gate_0 ;
static const uint8_t G1 = Gate_1 ;
static const uint8_t VS = VSense ;

/*
 * Serial interfaces
 */

// Serial1
#define PIN_SERIAL1_RX       (15ul)
#define PIN_SERIAL1_TX       (16ul)
#define PAD_SERIAL1_RX       (SERCOM_RX_PAD_1)
#define PAD_SERIAL1_TX       (UART_TX_PAD_0)

/*
 * SPI Interfaces
 */
#define SPI_INTERFACES_COUNT 1

#define PIN_SPI_MISO         (21u)
#define PIN_SPI_MOSI         (22u)
#define PIN_SPI_SCK          (23u)
#define PERIPH_SPI           sercom1
#define PAD_SPI_TX           SPI_PAD_3_SCK_1
#define PAD_SPI_RX           SERCOM_RX_PAD_2

#define SD_CHIP_SEL          (40u)
#define D0_CHIP_SEL          (28u)
#define D1_CHIP_SEL          (34u)

static const uint8_t MOSI = PIN_SPI_MOSI ;
static const uint8_t MISO = PIN_SPI_MISO ;
static const uint8_t SCK  = PIN_SPI_SCK ;

static const uint8_t SDCS	= SD_CHIP_SEL;
static const uint8_t D0CS	= D0_CHIP_SEL;
static const uint8_t D1CS	= D1_CHIP_SEL;

/*
 * Wire Interfaces
 */
#define WIRE_INTERFACES_COUNT 1

#define PIN_WIRE_SDA         (19u)
#define PIN_WIRE_SCL         (20u)
#define PERIPH_WIRE          sercom2
#define WIRE_IT_HANDLER      SERCOM2_Handler
#define WIRE_IT_HANDLER_0    SERCOM2_0_Handler
#define WIRE_IT_HANDLER_1    SERCOM2_1_Handler
#define WIRE_IT_HANDLER_2    SERCOM2_2_Handler
#define WIRE_IT_HANDLER_3    SERCOM2_3_Handler

static const uint8_t SDA = PIN_WIRE_SDA;
static const uint8_t SCL = PIN_WIRE_SCL;

/*
 * USB
 */
#define PIN_USB_HOST_ENABLE (24ul)
#define PIN_USB_DM          (25ul)
#define PIN_USB_DP          (26ul)

/*
 * I2S Interfaces
 */
#define I2S_INTERFACES_COUNT 0

#define I2S_DEVICE          0
#define I2S_CLOCK_GENERATOR 3

#ifdef __cplusplus
}
#endif

/*----------------------------------------------------------------------------
 *        Arduino objects - C++ only
 *----------------------------------------------------------------------------*/

#ifdef __cplusplus

/*	=========================
 *	===== SERCOM DEFINITION
 *	=========================
*/
extern SERCOM sercom0;
extern SERCOM sercom1;
extern SERCOM sercom2;
extern SERCOM sercom3;
extern SERCOM sercom4;
extern SERCOM sercom5;

extern Uart Serial1;

#endif
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

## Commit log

2020-10-04 v1.0 release
    [KiCad Schematic.kicad_pcb, KiCad Schematic.sch, v1_0.csv]
2020-10-09 rename folder for clarity. Versioning handled by git tags
    [KiCad Schematic.kicad_pcb, KiCad Schematic.sch, v1_0.csv]
2020-10-10 add power header
    [KiCad Schematic.kicad_pcb, KiCad Schematic.sch]
2020-10-21 wip building arduino configuration
2020-10-21 attempt to use board with arduino
2020-10-21 update arduino board files, not done yet
2020-10-23 finally working arduino board config
2020-10-28 got the drivers working still some bugs
2020-10-30 major arduino driver library updates
2020-10-30 steppers 2 and 3 output were flopped
2020-10-31 arduino version bump
2020-11-18 resolve a few issues in pcb design
    [KiCad Schematic.kicad_pcb, KiCad Schematic.sch]
2020-12-03 pcb optimizations and fixes to v1 arduino package
    [KiCad Schematic.kicad_pcb, KiCad Schematic.sch]
2020-12-05 pcb v2 release
    [KiCad Schematic.kicad_pcb, KiCad Schematic.sch, v2_0.csv]
2021-01-29 osr v2 package bugfix
    [variant.cpp]
2021-06-25 add new driver support and enable debug prints
2021-06-27 remove some debug delays from arduino library
2021-07-07 some work fixing board, bump arduino package version
    [2041Driver.sch, 5160Driver.sch, KiCad Schematic.kicad_pcb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]
2022-08-31 update prime board to v2
    [2041Driver.sch, 5160Driver.sch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]
